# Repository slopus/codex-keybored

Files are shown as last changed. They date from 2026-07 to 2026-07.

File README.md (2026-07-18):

<p align="center">
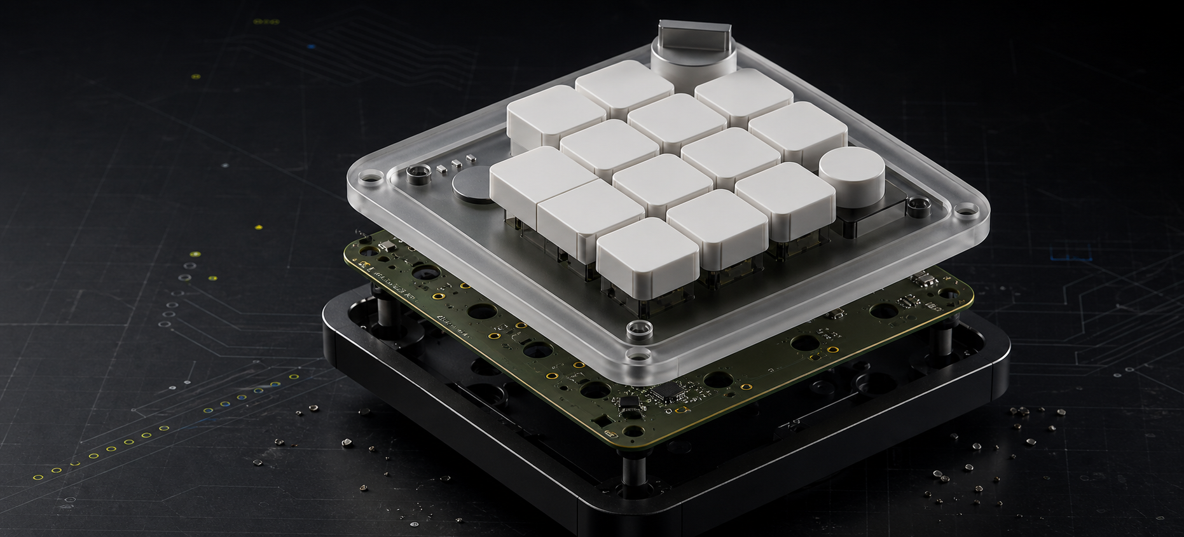
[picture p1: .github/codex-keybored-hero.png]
Exploded CODEX KEYBORED product render showing the CNC enclosure, six-layer PCB, switches, and controls
  
</p>

<h1 align="center">CODEX KEYBORED</h1>
<h3 align="center">WORK LOAFER EDITION · MECHANICS REV B · ELECTRONICS REV A2</h3>

<p align="center">
  A from-scratch, manufacturable parody of the Codex Micro: Fusion 360 mechanics,<br>
  four quoted CNC parts, a wired six-layer PCB, turnkey assembly instructions, and working USB HID firmware.
</p>

<p align="center">
  <a href="https://happy.engineering/codex-keybored/"><b>VIEW THE MANUFACTURING DOSSIER</b></a>
  &nbsp;·&nbsp;
  <a href="output/CODEX_KEYBORED_RevB_order_handoff.zip"><b>DOWNLOAD COMPLETE HANDOFF</b></a>
  &nbsp;·&nbsp;
  <a href="fusion/Codex_Micro_RevA.f3d"><b>OPEN FUSION ARCHIVE</b></a>
</p>

<p align="center">
  
  
  
  
</p>

---

<h1 align="center">THIS IS NOT A DISCLAIMER.<br>THIS IS THE WHOLE POINT.</h1>

<h1 align="center">ABSOLUTELY EVERYTHING HERE IS 100% VIBE-CODED.</h1>

<h1 align="center">
  FROM THE FIRST PROMPT TO FUSION 360, KICAD, GERBERS, FIRMWARE,<br>
  AND A REAL UPLOAD INTO JLCPCB + JLCCNC.
</h1>

<h2 align="center">
  THIS IS THE PRODUCT STORY: ONE CONTINUOUS VIBE<br>
  FROM A PUBLIC PRODUCT IMAGE<br>
  TO A REAL, QUOTED, FACTORY-READY HARDWARE STACK.
</h2>

<p align="center">
  <b>THE DELIGHTFUL PART IS THAT THE VIBE DID NOT STOP WHEN THE WORK BECAME PHYSICAL.</b><br>
  It crossed industrial design, parametric CAD, CNC drawings, multilayer electronics, component sourcing,
  USB firmware, factory testing, pricing, and vendor handoff. Every layer is editable, inspectable, and ready to continue.
</p>

## One vibe, all the way to the factory

Most vibe-coded projects end at a screenshot. This one kept going until the pixels became toleranced solids, the solids became quoted CNC parts, the control layout became a routed six-layer PCB, the PCB became Gerbers/BOM/CPL, the firmware became checksummed factory binaries, and the whole stack became live JLC manufacturing jobs.

That is the fun of this repository: the same conversational build loop moves through every engineering discipline without hiding the seams. “The aluminum base is slightly tilted” became a **5° Fusion body**. “Not a foot, a ring” became a purchased **JIS G‑65 O-ring**, a concentric retention groove, refreshed STEP/DXF/PDF exports, a successful JLCCNC import, a **$68.31** live base quote, and a cleaned cart. “I do not want to solder switches” became a both-side PCBA configuration, consigned-parts manifest, 74-position placement file, manual assembly contract, flashing procedure, and functional acceptance test.

| Vibe-coding pass | What was created | Where it became real |
|---|---|---|
| **Look closely** | Public renders were compared, scaled, and converted into an explicit confirmed/measured/inferred datum set | Research notes + manufacturing dossier |
| **Make it solid** | A parametric 108 × 108 mm assembly, corrected wedge, captured light pipe, joystick cap, and purchased continuous grip ring | Fusion 360 scripts + four STEP/DXF packages + G‑65 vendor reference |
| **Make it electronic** | A clean-room STM32F072 architecture, matrix, USB-C, touch, joystick, 24 RGB pixels, six copper layers | KiCad source + 0-error DRC + IPC netlist |
| **Make it behave** | USB HID firmware, neutral F13–F24 map, RGB safety limit, factory browser test | BIN/HEX/ELF + SHA-256 checksums |
| **Make it buildable** | LCSC mappings, BOM/CPL, specialty-parts sourcing, manual operations, inspection gates | Turnkey factory ZIP + controlled SOP |
| **Make the factory answer** | CAD and fabrication files were uploaded into authenticated quote flows | Four current JLCCNC items + JLCMC G‑65 ring + JLCPCB job Y5 |

```text
PROMPT → RESEARCH → DIMENSIONS → FUSION 360 → STEP/DXF → JLCCNC
                     ↓
              ELECTRICAL PLAN → KICAD → GERBER/BOM/CPL → JLCPCB
                     ↓
              FIRMWARE → FACTORY TEST → TURNKEY HANDOFF → A FEW FINAL SCREWS
```

The result is not “AI made a picture of a keyboard.” The result is a versioned hardware project in which a vibe-driven decision can be traced from sentence to parameter, from parameter to geometry or net, and from production file to a factory price. **That end-to-end continuity is the project.**

---

## The whole device, not just a render

| Mechanical | Electronics | Factory route |
|---|---|---|
| **108 × 108 mm** outer envelope | **90 × 90 mm**, six copper layers | **4 CNC parts** already quoted |
| **5°** machined aluminum wedge | STM32F072 + USB-C + TinyUSB | **5 PCBs / 2 PCBA** in turnkey job Y5 |
| Parametric Fusion assembly + STEP/DXF | 12 keys + encoder + touch + joystick | Specialty parts consigned to the factory |
| Black POM, clear PMMA, 6061-T6, NBR | 24 reverse-mount RGB pixels | Flash, functional test, and evidence in SOP |
| Controlled drawing pack | **0 DRC violations / 0 unconnected nets** | Customer closes only a few enclosure screws |

<table>
  <tr>
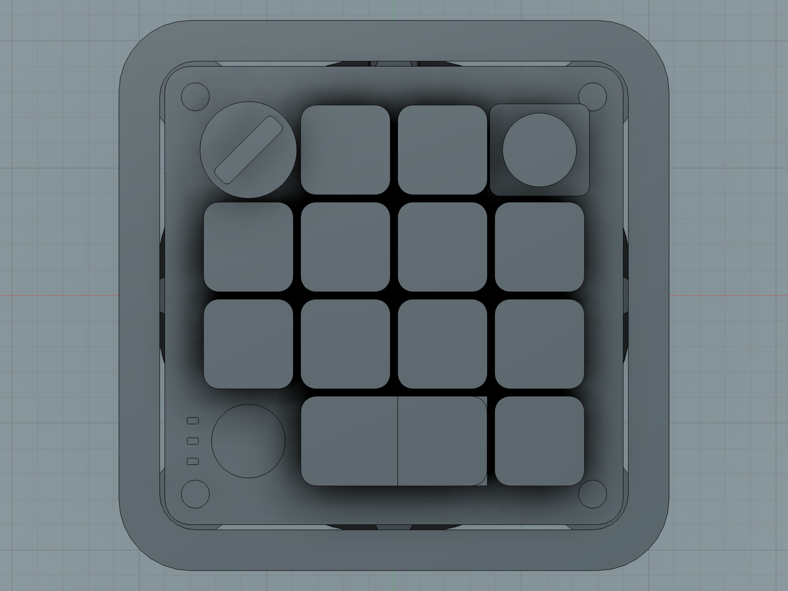
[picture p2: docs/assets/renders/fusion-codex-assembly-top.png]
Fusion 360 top view
    <td width="50%"><br><sub><b>FUSION 360 / TOP</b> — measured mechanical interface</sub></td>
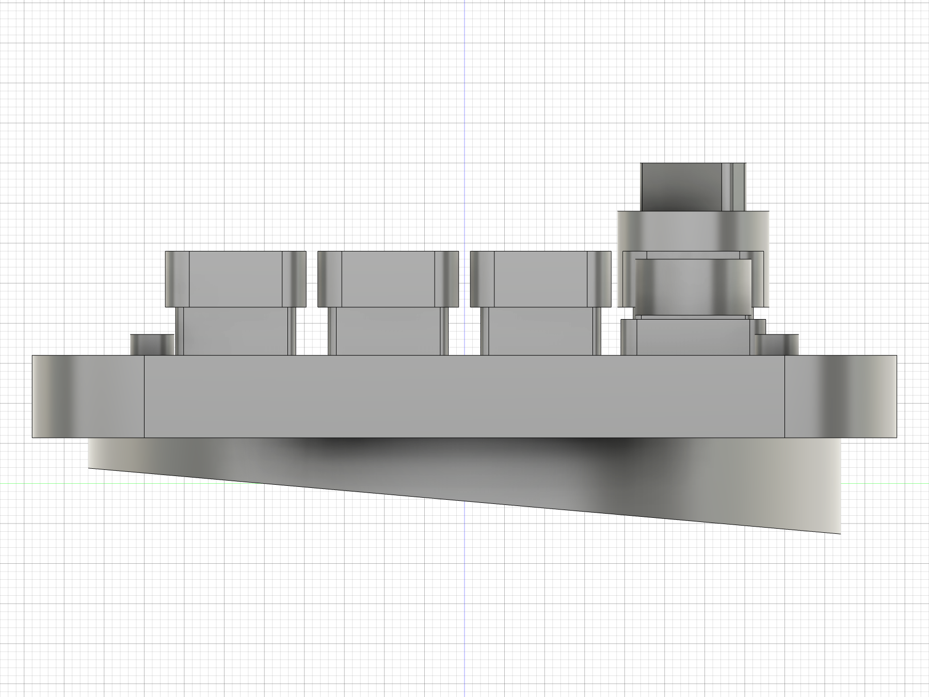
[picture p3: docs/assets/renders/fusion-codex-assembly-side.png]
Fusion 360 side view
    <td width="50%"><br><sub><b>FUSION 360 / SIDE</b> — corrected 5° wedge</sub></td>
  </tr>
  <tr>
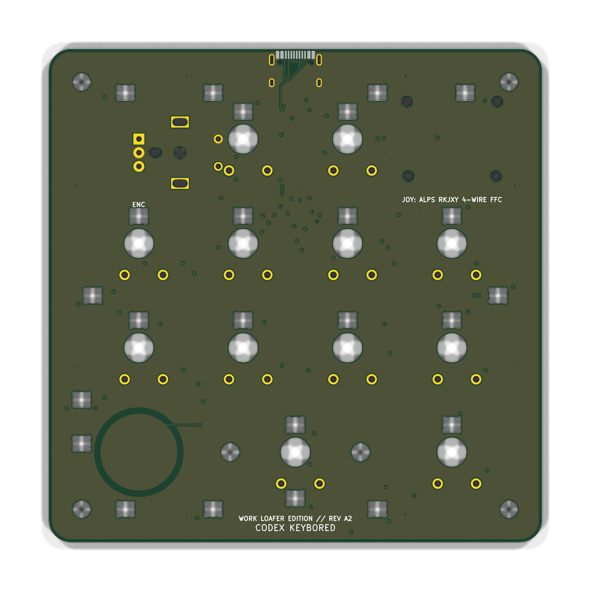
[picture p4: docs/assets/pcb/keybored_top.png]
CODEX KEYBORED PCB top
    <td width="50%"><br><sub><b>PCB / TOP</b> — WORK LOAFER EDITION silk</sub></td>
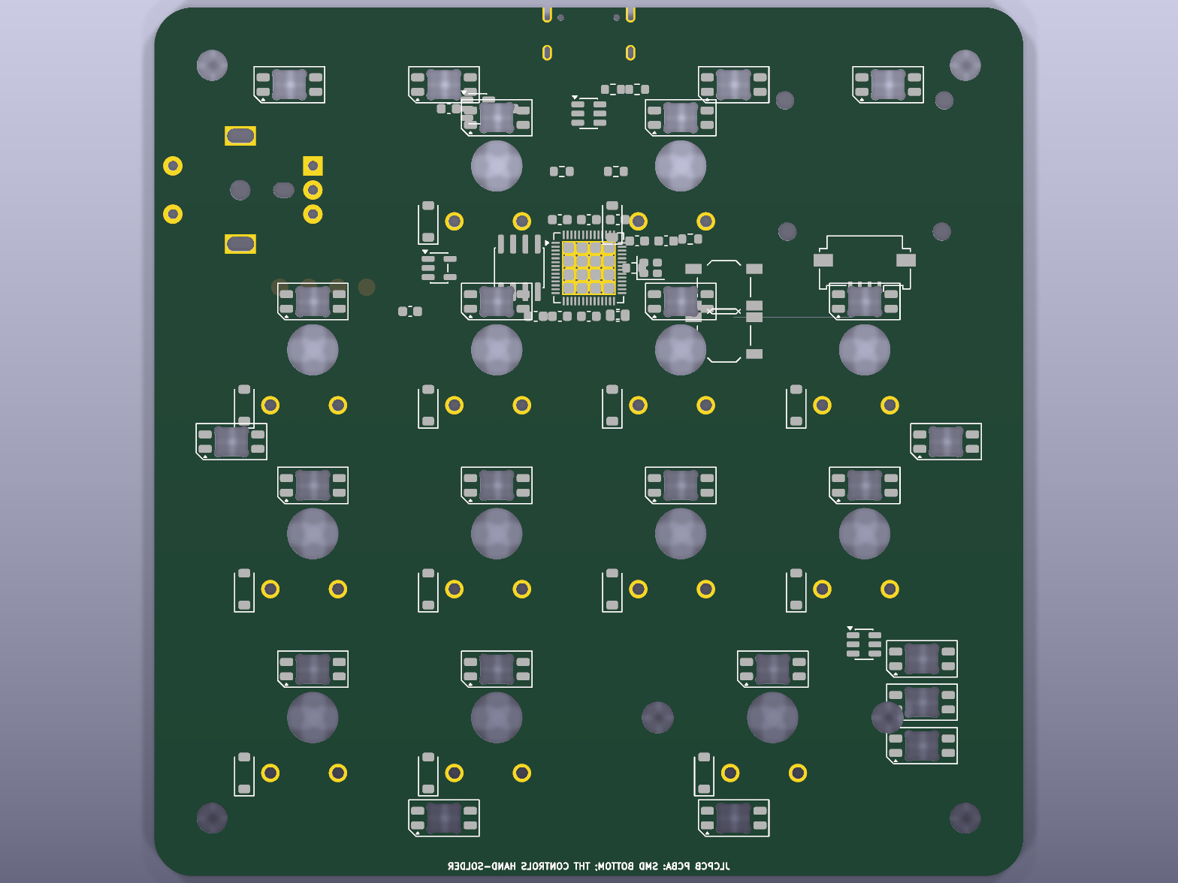
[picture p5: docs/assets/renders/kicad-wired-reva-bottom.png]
Populated PCB underside
    <td width="50%"><br><sub><b>PCB / BOTTOM</b> — controller island, power, matrix, RGB</sub></td>
  </tr>
</table>

## Yes: the factory does the hand work

> **ZERO SOLDERING AT HOME.** The production route asks JLC to place both-side SMD, manually install the twelve switches and encoder, fit the joystick/FFC, flash the STM32, exercise all 20 USB HID events, inspect all 24 RGB emitters, and install the caps on the primary unit. The customer-facing operation is enclosure closure after first-article approval.

The automatic JLC matcher uses the catalog-only [BOM](electronics/production/codex_micro_wired_revA_jlc_bom.csv) and [CPL](electronics/production/codex_micro_wired_revA_jlc_cpl.csv). The complete manual/secondary-operation contract is in the [turnkey SOP](electronics/production/CODEX_KEYBORED_RevA2_TURNKEY_SOP.md), [expanded BOM](electronics/production/codex_micro_wired_revA_turnkey_bom.csv), [74-position CPL](electronics/production/codex_micro_wired_revA_turnkey_cpl.csv), and [consigned-parts manifest](electronics/production/codex_micro_wired_revA_consigned_parts.csv).

```text
SOURCE SPECIALTY PARTS  →  BOTH-SIDE PCBA  →  MANUAL CONTROLS
         →  FLASH + FUNCTION TEST  →  PHOTO EVIDENCE  →  ENCLOSURE CLOSURE
```

## Live manufacturing snapshot

Quotes were captured in an authenticated JLC session on **July 17, 2026**. Prices are dynamic and exclude possible tax, duty, and engineering-review additions.

| Job | Configuration | Captured price |
|---|---|---:|
| CM2-001 upper housing | CNC polished black POM, qty 1 | **$88.97** |
| CM2-002 angled weight | CNC 6061-T6, 5° wedge + G‑65 groove, qty 1 | **$68.31** |
| CM2-003 light pipe | CNC clear cast PMMA, polished edges + frosted face, qty 1 | **$45.70** |
| CM2-004 joystick cap | CNC POM fit prototype, qty 1 | **$19.42** |
| CM2-005 continuous grip ring | JLCMC AMFG-P5-A65-65 / black NBR 65A, qty 1 | **$0.16** |
| **Mechanical subtotal** | Four current CNC parts + purchased ring | **$222.56** |
| **JLCPCB turnkey base** | Five PCBs + two both-side Standard PCBA | **$193.01** |
| **Captured manufacturing floor** | Mechanical merchandise + PCBA base, before manual review, special parts, tax/duty/shipping | **$415.57** |

<p align="center">
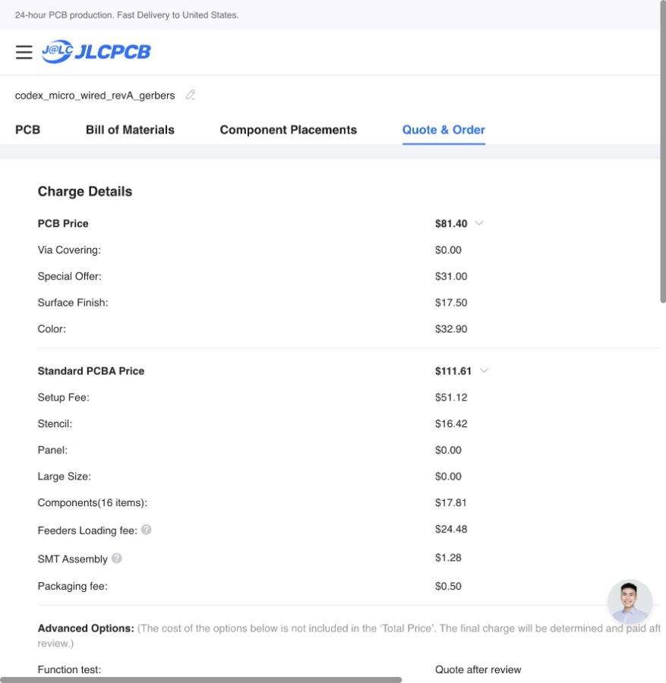
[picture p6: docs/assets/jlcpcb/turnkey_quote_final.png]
JLCPCB turnkey quote configuration
  
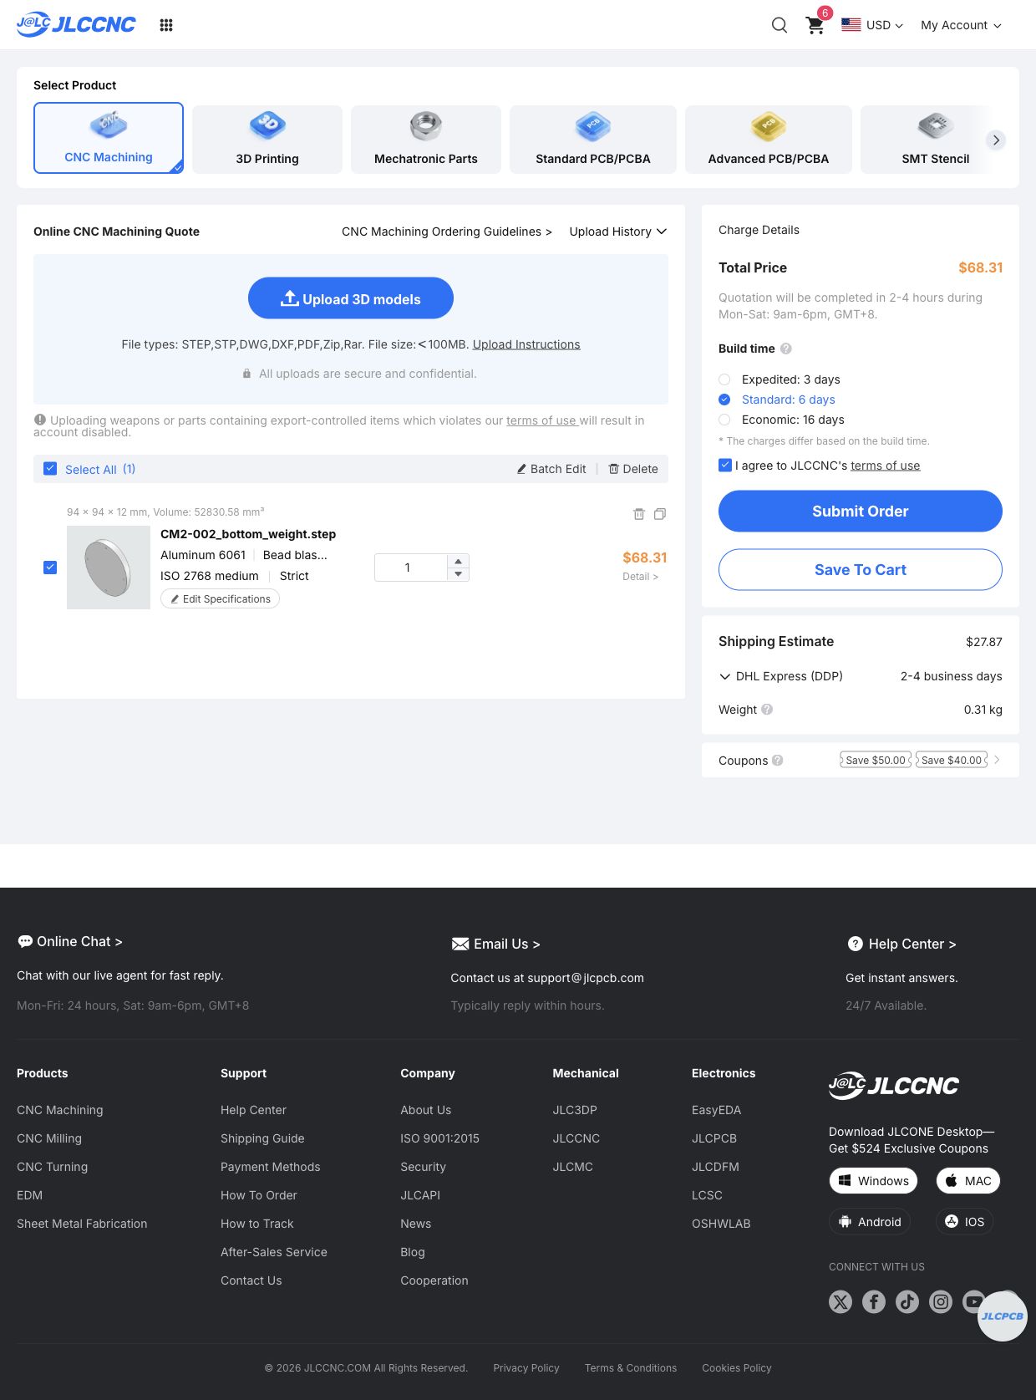
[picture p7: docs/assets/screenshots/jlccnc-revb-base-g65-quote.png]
JLCCNC Rev B ring-groove base quote
  
</p>

The **$193.01** PCB/PCBA figure is a captured base, not a promise of a finished-device total. Programming, functional test, secondary manual operations, and consigned-part handling remain quote-after-review. The saved cart proves that the geometry and six-layer board can enter the vendor workflow; JLC engineering approval is still the gate before payment.

## What is actually in the repository

| Area | Source of truth | Ready-to-send artifact |
|---|---|---|
| Fusion mechanics | [`fusion/build_codex_micro_mechanical.py`](fusion/build_codex_micro_mechanical.py) | [`Codex_Micro_RevA.f3d`](fusion/Codex_Micro_RevA.f3d) |
| CNC geometry | Fusion BRep bodies | [`cnc/STEP/`](cnc/STEP/) + [`cnc/DXF/`](cnc/DXF/) |
| CNC dimensions | Parametric model + controlled notes | [`CM2_CNC_Drawing_Pack_RevB.pdf`](cnc/drawings/CM2_CNC_Drawing_Pack_RevB.pdf) |
| PCB connectivity/layout | [`codex_micro_wired_revA.kicad_pcb`](electronics/kicad/codex_micro_wired_revA.kicad_pcb) | [Gerber/drill ZIP](electronics/production/codex_micro_wired_revA_gerbers.zip) |
| Assembly data | Board-derived generator | [JLC BOM](electronics/production/codex_micro_wired_revA_jlc_bom.csv) + [JLC CPL](electronics/production/codex_micro_wired_revA_jlc_cpl.csv) |
| Principle schematic | Final routed connectivity | [Three-sheet PDF](output/pdf/CODEX_KEYBORED_RevA2_schematic.pdf) + [IPC-D-356](electronics/production/netlist/CODEX_KEYBORED_RevA2.ipc) |
| Firmware | [`firmware/stm32/`](firmware/stm32/) | [BIN](firmware/stm32/release/codeks_keybored_revA.bin) + [HEX](firmware/stm32/release/codeks_keybored_revA.hex) + [checksums](firmware/stm32/release/SHA256SUMS.txt) |
| Factory contract | Mechanics Rev B + electronics Rev A2 | [Complete order handoff ZIP](output/CODEX_KEYBORED_RevB_order_handoff.zip) + [mechanical factory ZIP](output/CODEX_KEYBORED_RevB_mechanical_factory_handoff.zip) |
| Full report | Evidence, screenshots, prices, sources | [Single-page dossier](https://happy.engineering/codex-keybored/) + [Rev B PDF](output/pdf/CODEX-KEYBORED-Manufacturing-Dossier-RevB.pdf) |

## Electrical architecture

- STM32F072CBT6, 128 KB flash, crystal-less HSI48 + CRS USB.
- USB-C device input, dual 5.1 kΩ CC resistors, USBLC6 ESD protection.
- Six layers: `F.Cu`, GND plane, two signal layers, `+5V` plane, `B.Cu`.
- Twelve low-profile matrix switches plus clickable encoder.
- Capacitive touch and two-channel analog planar joystick.
- 24 × SK6812MINI-E: twelve per-key, nine underglow, three status.
- Build-verified TinyUSB firmware with BIN/HEX/ELF artifacts and a browser factory test.
- Housing interface intentionally remains compatible with a future replacement ESP32-S3/BLE board.

<p align="center">
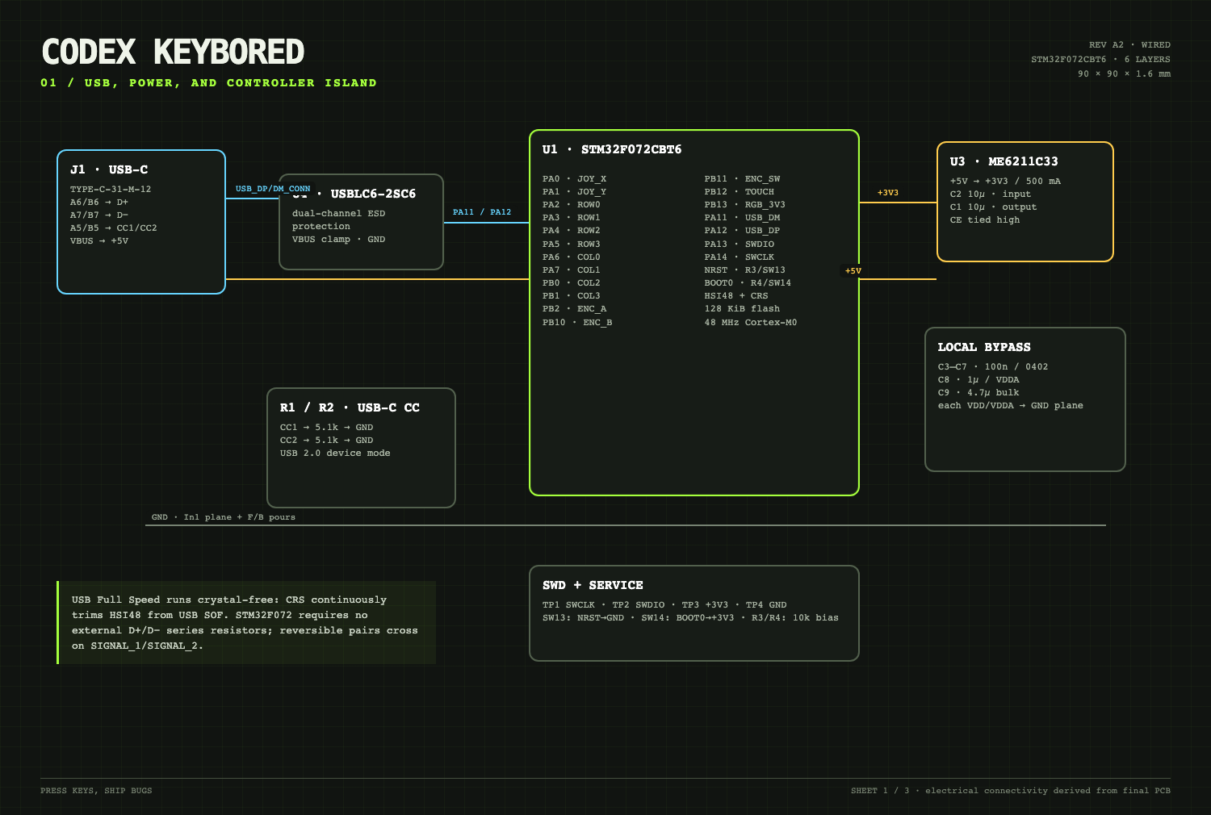
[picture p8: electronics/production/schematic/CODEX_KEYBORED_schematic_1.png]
USB power and STM32 schematic
  
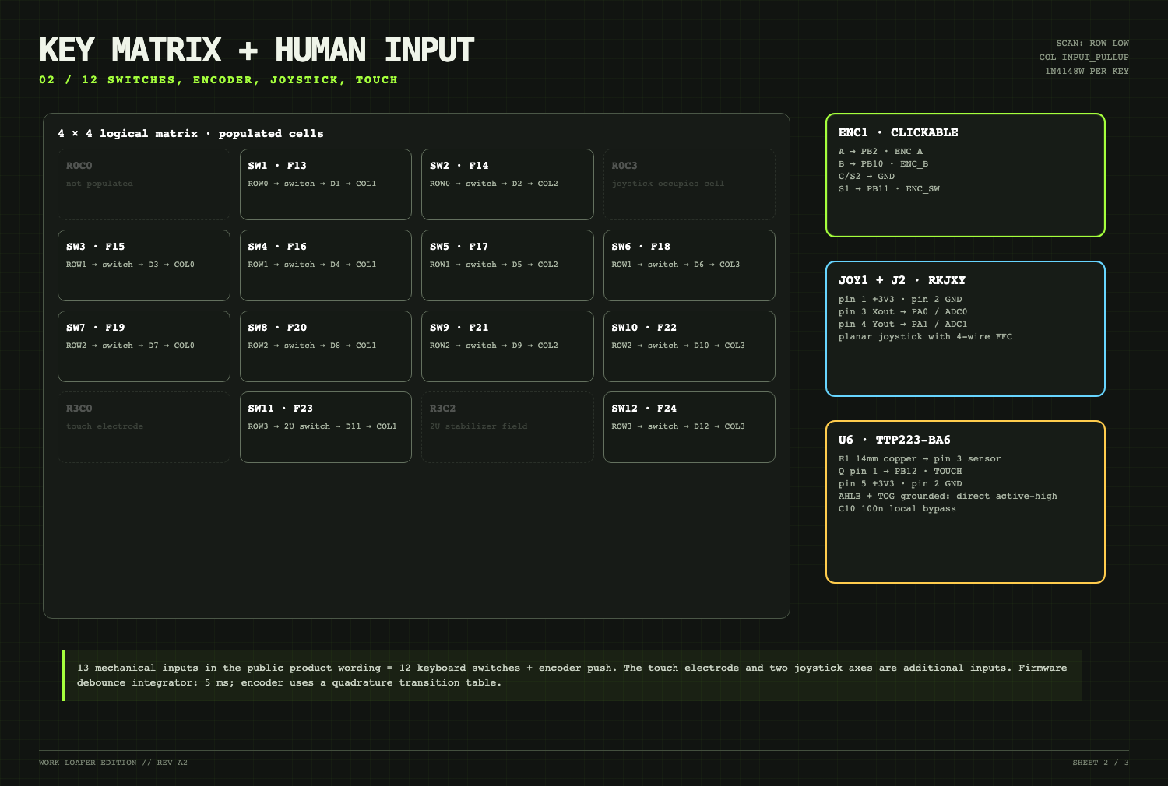
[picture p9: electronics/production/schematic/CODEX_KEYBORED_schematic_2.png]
Keyboard matrix and controls schematic
  
</p>

## Mechanical datum set

The coordinate origin is the device center. `+Y` points toward the rear edge; `+Z` points upward.

| Parameter | Value | Confidence | Basis |
|---|---:|---|---|
| Key pitch | 19.05 mm | **CONFIRMED** | Work Louder MX keycap specification |
| Installed keyboard switches | 12 | **CONFIRMED** | Visible layout + Creator Micro 2 specification |
| Total mechanical switch inputs | 13 | **CONFIRMED** | Includes encoder push |
| Outer envelope | 108 × 108 mm | **MEASURED** | Official top render scaled from key centers |
| Top PCB/panel | 90 × 90 × 1.6 mm | **MEASURED / INFERRED** | Render scale + standard PCB thickness |
| PCB screw pitch | 78 × 78 mm | **MEASURED** | Provisional ±0.5 mm |
| Upper housing | 108 × 108 × 10.3 mm, R14 | **MEASURED** | Public front/side/top renders |
| Aluminum bottom | Ø94 mm, 3.8→12.0 mm, 5° | **MEASURED / INFERRED** | Side profile + CNC construction |
| G‑65 retention groove | Ø67.5 mm centerline × 3.6 W × 2.2 D | **ENGINEERED** | G‑65 section, screw clearance, 1.6 mm minimum Al floor |
| Continuous grip ring | JIS B 2401 G‑65, ID 64.4, section 3.1, OD 70.6 mm | **PURCHASED / VERIFIED** | JLCMC AMFG-P5-A65-65 |
| Joystick candidate | Alps RKJXY1000006 | **CANDIDATE** | Available electrical/mechanical sibling |

Confidence language is deliberate:

- **CONFIRMED** — explicitly published by OpenAI, Work Louder, or a component manufacturer.
- **MEASURED** — scaled from a public, near-orthographic product render.
- **INFERRED** — a manufacturable placeholder that still requires physical first-article inspection.
- **ENGINEERED** — a derived interface sized from known parts, tolerances, and adjacent clearances.
- **PURCHASED / VERIFIED** — an exact orderable catalog part with checked dimensions and a live cart entry.

## CNC material directions

The current quoted Rev B build uses polished black POM for the upper housing and joystick cap, black-anodized 6061-T6 for the 5° base, clear cast PMMA for the captured light pipe, and a purchased black NBR G‑65 ring. A wood upper remains a future material experiment, but it is not the current cart configuration.

All four STEP files passed JLC's automated CNC import. The current bottom was explicitly corrected from an early flat disc to the observed **5° wedge**, then revised again with the G‑65 retention groove before the **$68.31** configuration was saved. Obsolete flat/no-groove parts and individual rubber feet were removed from the cart.

## Reproduce it

1. Open or create the Fusion document named `Codex`, then run [`fusion/build_codex_micro_mechanical.py`](fusion/build_codex_micro_mechanical.py).
2. Export/audit CNC bodies with the scripts in [`fusion/`](fusion/) and compare them with the controlled drawing pack.
3. Open the board in KiCad 10 and verify the committed DRC report before regenerating fabrication data.
4. Build the STM32 target from [`firmware/stm32/`](firmware/stm32/) or use the checksummed release image.
5. Upload the Gerber ZIP, JLC BOM/CPL, CNC STEP files, drawing pack, and turnkey factory ZIP.
6. Do not authorize production until JLC DFM, polarity/rotation, manual-operation scope, and first-article dimensions are reviewed.

## Prototype status and provenance

This is an **independent private prototype**, reconstructed from official public product renders and published platform/component documentation. It is not an official OpenAI or Work Louder CAD/electronics release, is not affiliated with or endorsed by either company, and contains no leaked manufacturing data.

The digital production gate is clean: Gerbers, drill files, BOM/CPL, IPC netlist, three-sheet principle schematic, firmware, STEP/DXF, drawings, and vendor quote evidence are present. The physical gate is still open: no fabricated Rev A2 board has completed electrical bring-up, EMC evaluation, or dimensional fit-check. Use a current-limited supply, verify the 3.3 V rail and SWD first, and treat the first order as an engineering prototype.

Primary research links and detailed source notes live in the [manufacturing dossier](https://happy.engineering/codex-keybored/) and [`firmware-and-compliance-notes.md`](firmware-and-compliance-notes.md).

---

<h2 align="center">PRESS KEYS. SHIP BUGS.</h2>
<p align="center"><b>CODEX KEYBORED / WORK LOAFER EDITION / MECHANICS REV B + ELECTRONICS REV A2</b></p>

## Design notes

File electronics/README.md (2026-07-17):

# CODEX KEYBORED Wired Rev A2 — production notes

This directory contains a mechanically compatible **wired prototype**, not a
reverse-engineered copy of the unpublished Work Louder electronics.  The board
uses a clean-room STM32F072/USB-C design and keeps the 90 × 90 mm top-panel outline
so a later ESP32-S3/BLE controller can replace it without changing the housing.

## Electrical architecture

- Six copper layers: `F.Cu`, ground plane, two signal layers, `+5V` plane,
  `B.Cu`.
- STM32F072CBT6 with 128 KB internal flash, HSI48 + CRS crystal-less USB, and
  ME6211 3.3 V LDO. No external flash or crystal is required.
- USB-C device input with two 5.1 kΩ CC resistors and USBLC6 ESD protection.
  The reversible connector pairs cross on `SIGNAL_1` / `SIGNAL_2` before PA11/PA12.
- Twelve Gateron KS-33 / wrk. LP1-family matrix switches plus encoder push.
- Clickable encoder, TTP223-class touch input and two-channel analog joystick.
- 24 SK6812MINI-E pixels through a 5 V-compatible AHCT buffer: 12 per-key,
  nine perimeter underglow and three status LEDs.
- NRST, BOOT0 and SWD bring-up access.

The PCB is generated from `generate_wired_reva.py`; it deliberately does not
depend on a GUI schematic editor. Pad/net assignments in the generated KiCad
board are the electrical source of truth. `generate_jlc_outputs.py` derives the
assembly files from that same board and fails if an unmapped fitted reference is
encountered.

Final automated checks report **0 DRC violations and 0 unconnected nets**.
`docs/schematic.html` is a three-sheet engineering principle schematic derived
from that final connectivity; the IPC-D-356 file is the machine-readable netlist.

## Production files

- `production/codex_micro_wired_revA_gerbers.zip` — JLCPCB fabrication upload.
- `production/codex_micro_wired_revA_jlc_bom.csv` — JLCPCB BOM with LCSC IDs.
- `production/codex_micro_wired_revA_jlc_cpl.csv` — machine placement file.
- `production/codex_micro_wired_revA_turnkey_bom.csv` — both-side BOM including
  consigned/manual controls and factory-programming buttons.
- `production/codex_micro_wired_revA_turnkey_cpl.csv` — all 74 machine and
  manual placement centers.
- `production/codex_micro_wired_revA_consigned_parts.csv` — direct-to-JLC
  sourcing quantities for WRK-LP1, joystick, keycaps, and dial cap.
- `production/CODEX_KEYBORED_RevA2_TURNKEY_SOP.md` — assembly, programming,
  functional test, evidence, and delivery acceptance instructions.
- `production/codex_micro_wired_revA_hand_assembly.csv` — legacy list of parts
  omitted by the saved bottom-only baseline quote.
- `production/codex_micro_wired_revA_drc.json` — final clean DRC report.
- `production/netlist/CODEX_KEYBORED_RevA2.ipc` — IPC-D-356 connectivity.
- `production/schematic/CODEX_KEYBORED_RevA2_schematic.pdf` — principle schematic.

JLC cart job Y5 / `SMT026071763199-3086316A` is Standard PCBA on **both sides**:
five PCBs and two assembled boards. Its automatic matcher uses the catalog-only
`*_jlc_bom.csv` and `*_jlc_cpl.csv` and confirmed all 16 groups. The expanded
`turnkey` BOM/CPL and consigned-parts CSV are factory engineering references for
manual installation of `SW1–SW12`, the encoder, and the joystick/FFC. The
captured base is $193.01; programming, FCT, and manual engineering remain
quote-after-review. These are contract-assembly operations—not customer work.
Review every polarity/rotation and obtain JLC engineering approval before
confirming a paid order.

## Bring-up gate

This is a prototype design and has not been electrically tested on fabricated
hardware. Before attaching a computer, use a current-limited 5 V supply and
verify the 3.3 V rail, inspect for shorts, confirm SWD/NRST, and only then
enumerate USB. The supplied firmware limits
RGB channels to 4/255; still populate the chain last, or depopulate its bulk
capacitor/level shifter for the earliest rail-only bring-up.

The selected LCSC mappings and exact quantities are listed in the BOM. Part
stock and JLCPCB assembly classification can change; a successful web quote is
not an engineering substitute for the vendor's final DFM and placement review.

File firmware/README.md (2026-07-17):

# CODEX KEYBORED firmware

The production Rev A2 target is the STM32F072CBT6 project in [`stm32/`](stm32/).
It enumerates as a driverless USB HID keyboard and implements the complete PCB
pin map: 12-key matrix, clickable encoder, capacitive touch, two-axis joystick
ADC and a conservative 24-pixel SK6812 status/underglow chain.

The older root-level RP2040 proof-of-concept sources and `release/` binaries are
retained only as design history. They **must not** be flashed onto Rev A2.

See [`stm32/README.md`](stm32/README.md) for the reproducible build, SWD flash
command and first-power checklist.

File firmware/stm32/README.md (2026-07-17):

# STM32F072 wired Rev A2

This build targets the directly assembled STM32F072CBT6 on the single 90 x 90
mm PCB. USB Full Speed uses the internal HSI48 oscillator disciplined by CRS;
there is no crystal and no removable controller module.

## Behavior

- 12 keys send F13–F24 in physical order.
- Encoder rotation sends Page Up/Page Down; push sends keypad Enter.
- Capacitive touch sends F12.
- Joystick thresholds send the four arrow keys.
- 24 SK6812MINI-E pixels are limited to channel values 0–4/255 during bring-up.
- USB identity: development VID/PID `CAFE:4B44`, product `CODEX KEYBORED Rev A2`.

## Reproducible build

TinyUSB is pinned at commit `aa410008e8e74b0727f8c30a1ec109ff2c37efc6`.
The large upstream checkout is intentionally not stored in this repository;
the tracked bootstrap script fetches only the required STM32F0 dependencies and
installs the local `codeks_keybored` board definition. Use an Arm GNU embedded
toolchain that includes newlib (verified with official Arm GNU Toolchain
15.2.Rel1):

```sh
sh firmware/stm32/fetch_dependencies.sh
cmake -S firmware/stm32 -B firmware/stm32/build-arm15 -G Ninja \
  -DFAMILY=stm32f0 -DBOARD=codeks_keybored -DTOOLCHAIN=gcc
cmake --build firmware/stm32/build-arm15 -j
```

The verified build uses 16,548 bytes of 128 KiB flash and 2,448 bytes of 16 KiB
RAM. Flash `release/codeks_keybored_revA.hex` through SWD (TP1 SWCLK, TP2 SWD,
TP3 3V3, TP4 GND), for example:

```sh
openocd -f interface/stlink.cfg -f target/stm32f0x.cfg \
  -c "program release/codeks_keybored_revA.hex verify reset exit"
```

## Verification boundary

The artifacts are compiler/linker verified, not hardware verified. Power the
first assembly from a current-limited 5 V supply before attaching a computer.
Confirm 3.3 V, SWD access, USB enumeration, every switch/encoder direction,
joystick center/endpoints, touch polarity and all RGB orientations. The
bit-banged SK6812 timing is deliberately isolated in `main.c`; verify it on an
oscilloscope and tune the delay constants for the assembled board before
raising brightness. Replace the development USB VID/PID before distribution.

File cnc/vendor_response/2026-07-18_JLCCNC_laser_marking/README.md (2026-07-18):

# JLCCNC laser-marking response — CM2-002 Rev B

This package answers JLCCNC's request to replace the too-fine machined lettering on the black-anodized aluminum bottom weight with laser marking.

## Send these three files

1. `CM2-002_LASER_ARTWORK_ONLY_RevB.dxf` — production laser artwork only. This is the safest file for import into the laser CAM system.
2. `CM2-002_LASER_PLACEMENT_REFERENCE_RevB.dxf` — the same artwork plus Ø94 part outline, groove, holes, and rear datum on clearly named `DO_NOT_MARK` layers.
3. `CM2-002_LASER_PLACEMENT_APPROVAL_RevB.pdf` — human-readable 1:1 approval sheet specifying side, orientation, process order, and appearance.

Copy the body of `EMAIL_REPLY.txt` into the reply email and attach the three files individually. Do not rely on the ZIP alone if their mail gateway blocks archives.

## Controlled manufacturing intent

- Part: `CM2-002_bottom_weight.step`
- CNC item: `CNC2607185001881-3086316A`
- Surface: underside / desk-facing angled plane
- Orientation: `+Y` is rear / thick edge / USB side
- Process: fine bead blast → black matte anodize → laser mark
- Appearance: natural aluminum / silver artwork on black
- Marking: solid/hatch-filled compound glyphs, with letter counters preserved
- Production layer: `LASER_MARK` only
- Coordinates: millimeters, scale 1:1, origin at part center
- Main line: `CODEX KEYBORED`, Arial Bold, 4.2 mm nominal CAD font size; outlined envelope 39.498 × 3.109 mm; center `(0, +4.000)`
- Strapline: `ABSOLUTELY VIBE-CODED`, Arial Regular, 2.1 mm nominal CAD font size; outlined envelope 27.122 × 1.556 mm; center `(0, −4.000)`

The DXFs contain no live font objects. The artwork consists of closed `LWPOLYLINE` contours so the factory does not need the source fonts.

## Reference-only files

- `CM2-002_LASER_PLACEMENT_PREVIEW_RevB.svg` — screen preview.
- `CM2-002_LASER_GEOMETRY_RevB.json` — machine-readable source geometry and measured bounds.

These are included for traceability but do not need to be emailed unless requested.

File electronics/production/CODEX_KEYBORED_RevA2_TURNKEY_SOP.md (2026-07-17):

# CODEX KEYBORED Rev A2 — turnkey assembly and test SOP

**Build intent:** deliver one complete, programmed, electrically tested control pad and one programmed spare PCBA. The customer performs no soldering. Home assembly is limited to the controlled enclosure screws after first-article fit approval.

## Order configuration

- Service: JLCPCB **Standard PCBA**, both sides.
- Fabrication: 6-layer FR-4, 90 × 90 × 1.6 mm, white mask, black silk, ENIG.
- PCB quantity: 5. PCBA quantity: 2.
- Submit `codex_micro_wired_revA_jlc_bom.csv` and `codex_micro_wired_revA_jlc_cpl.csv` to JLC's automatic catalog matcher. Use the expanded `turnkey` BOM/CPL and consigned-parts CSV as the manual-assembly engineering reference.
- Depanel and remove JLC edge rails before delivery.
- Enable component photo confirmation, programming/function test, and a PCBA remark referencing this SOP.
- Customer-consigned parts must be received and booked into the JLC parts library before production.

## Assembly sequence

1. Assemble all bottom-side SMD parts, including reverse-mount RGB LEDs, J2, RESET, and BOOT0.
2. Assemble the top-side USB-C connector J1.
3. Manually insert and solder twelve WRK-LP1 switches at SW1–SW12. Seat every switch body flush and square to the PCB before soldering.
4. Manually insert and solder EC11E09444A8 at ENC1. Keep the shaft normal to the PCB.
5. Mechanically install RKJXY1000006 at JOY1 and lock its four-wire flex tail into J2. Do not crease the tail.
6. Clean and visually inspect all manual joints. Verify no switch body is lifted by more than 0.15 mm and the 2U key remains centered over SW11.
7. Program both PCBAs, run the functional test below, and identify the passing units as PRIMARY and SPARE.
8. On PRIMARY only, fit the twelve final keycaps, the 2U stabilizer/cap, the dial cap, and the joystick cap after electrical test. Do not glue caps.
9. Bag PRIMARY and SPARE separately in ESD-safe packaging. Include unused switches and unused PCB blanks.

## Firmware programming

- Target: STM32F072CBT6.
- Image: `../../firmware/stm32/release/codeks_keybored_revA.bin` at address `0x08000000`, or the corresponding HEX file.
- Preferred production route: SWD pogo contact at TP1/TP2/TP3/TP4 (SWCLK/SWDIO/3V3/GND).
- Alternate route: hold BOOT0 (SW14), pulse RESET (SW13), release BOOT0 after USB DFU enumerates, then program with STM32CubeProgrammer.
- After programming, power-cycle and confirm USB HID enumeration as `CODEX KEYBORED`.

## Functional acceptance test

Open `../../firmware/factory_key_test.html` in a Chromium browser on the test host, focus the page, then exercise every control.

- SW1–SW12: all F13–F24 indicators must pass exactly once.
- Encoder push: Keypad Enter indicator must pass.
- Encoder clockwise/counter-clockwise: Page Up and Page Down must both pass.
- Joystick: Left, Right, Up, and Down must all pass and return to neutral.
- Touch pad: F12 indicator must pass.
- RGB: all 24 emitters must illuminate; installed-key LEDs change state when their key is pressed.
- USB: reconnect three times; the device must enumerate each time without a warning.
- No switch may chatter visibly in the browser tester during ten presses.

Save one photo of the completed PRIMARY top side, one bottom-side photo, and one screenshot of the all-green factory tester. Do not ship a failed unit as PRIMARY.

## Customer-side work

After dimensional first-article approval, the customer only installs the completed PRIMARY PCBA/light pipe into the CNC parts using the four specified enclosure screws. No soldering, firmware flashing, switch insertion, or key testing is assigned to the customer.

## Quote status

JLC cart job Y5 / `SMT026071763199-3086316A` is configured for five PCBs and two both-side Standard PCBA units. Its captured base is `$193.01` (`$81.40` PCB + `$111.61` PCBA). Function testing, the PCBA remark/manual work, and consigned WRK-LP1/RKJXY operations remain quote-after-review; the base is not the final turnkey price.

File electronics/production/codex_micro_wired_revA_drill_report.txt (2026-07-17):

Drill report for codex_micro_wired_revA.kicad_pcb
Created on 2026-07-17T12:11:25

Copper Layer Stackup:
    =============================================================
    L1 :  F.Cu                      front
    L2 :  GND_PLANE                 in1
    L3 :  SIGNAL_1                  in2
    L4 :  SIGNAL_2                  in3
    L5 :  +5V_PLANE                 in4
    L6 :  B.Cu                      back

Drill file 'codex_micro_wired_revA-PTH.drl' contains
    plated through holes:
    =============================================================
    T1  0.200mm  0.0079"  (94 holes))
    T2  0.300mm  0.0118"  (8 holes))
    T3  0.600mm  0.0236"  (4 holes)  (with 4 slots)
    T4  1.000mm  0.0394"  (5 holes))
    T5  1.200mm  0.0472"  (24 holes))
    T6  1.500mm  0.0591"  (2 holes)  (with 2 slots)

    Total plated holes count 137

Drill file 'codex_micro_wired_revA-NPTH.drl' contains
    unplated through holes:
    =============================================================
    T1  0.650mm  0.0256"  (2 holes))
    T2  1.600mm  0.0630"  (1 hole)  (with 1 slot)
    T3  1.900mm  0.0748"  (4 holes))
    T4  2.100mm  0.0827"  (1 hole)
    T5  3.200mm  0.1260"  (4 holes))
    T6  3.300mm  0.1299"  (2 holes))
    T7  5.300mm  0.2087"  (12 holes))

    Total unplated holes count 26

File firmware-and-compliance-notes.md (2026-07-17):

# Firmware, Bluetooth, FCC, and ISED evidence

## Public firmware inspected

Work Louder published a diagnostic CM2 image in its battery-charging support
thread:

`https://github.com/worklouder/input-releases-internal/releases/download/battery.charging.diagnostic/firmware_cmv2_v0.3.0-rc.2_merged.bin`

`esptool 5.2.0 image-info` identifies the 2,117,568-byte merged image as:

- target: **ESP32-S3** (chip ID 9);
- flash: **16 MB**, DIO, 80 MHz;
- bootloader: ESP-IDF **5.3.2.250210**;
- compile time: 2026-01-16 11:32:52;
- image checksum and SHA-256 validation hash both valid.

Selected plain-text symbols/strings in the image:

- `Work Louder`, `Creator Micro 2`;
- `NimBLE`, `TinyUSB`, `ESP32 Keyboard`;
- `max77972_regs`, `Initializing battery IC`;
- GPIO initialization for rear button, USB detect, layer LEDs, touch pad,
  encoder A/B/switch, top-board power, and charge enable;
- `Switching to BLE slot %d`;
- self-test for key matrix, encoder rotation/press, touch button, rear button,
  and battery voltage/current;
- default keymap rows of 2 / 4 / 4 / 3 keyboard inputs.

Analog Devices describes MAX77972 as a one-cell Li-ion/Li-poly charger and fuel
gauge with USB-C CC and BC1.2 detection:
`https://www.analog.com/en/products/MAX77972.html`.

The binary proves the MCU family and charger IC used by the firmware build. It
does **not** prove whether production uses a bare ESP32-S3, an Espressif module,
or a custom certified radio module.

## FCC result

The official FCC EAS grantee-registration dataset was searched for:

- `Work Louder`
- `Worklouder`
- `Louder`
- `Creator Micro`
- `3300 Av Troie`

All returned zero records. The official exterior bottom render carries an FCC
logo but no visible FCC ID. This is consistent with, but does not prove, use of
a pre-certified radio module or a compliance route that does not create a Work
Louder grantee entry.

Official FCC grantee dataset:
`https://opendata.fcc.gov/resource/3b3k-34jp.json`

## Canadian ISED result

The official ISED Company Name Search returned no result for `Work Louder`.
The official Radio Equipment List returned no result for either:

- Product Marketing Name: `Creator Micro 2`
- Company Name: `Work Louder`

Search entry point:
`https://www.ised-isde.canada.ca/site/spectrum-management-system/en/equipment-certification-and-registration-services`

## What will resolve the radio module exactly

The next definitive evidence is a straight-on macro photograph of both sides of
the lower PCB after lifting the four top screws and disconnecting the FFC. The
required details are the ESP/module shield marking, antenna layout, FCC/ISED
text, crystal marking, USB-C connector, and MAX77972 area. Until that image
exists, the PCB should reserve a certified ESP32-S3 module keep-out rather than
copy an unverified antenna implementation.

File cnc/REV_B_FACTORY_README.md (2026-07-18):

# CODEX KEYBORED — Mechanical Rev B factory handoff

This package is the controlled mechanical first-article set for one device.
Submit four custom parts to JLC CNC and purchase one standard continuous grip
ring from JLCMC. Do not substitute individual rubber feet.

## Order exactly these items

| ID | File / part number | Qty | Material and finish | Live price 2026-07-17 |
|---|---|---:|---|---:|
| CM2-001 | `STEP/CM2-001_upper_housing.step` | 1 | POM (Black); no bead blast; polish cosmetic A-surfaces | $88.97 |
| CM2-002 | `STEP/CM2-002_bottom_weight.step` | 1 | 6061-T6; fine bead blast + matte black anodize; strict appearance | $68.31 |
| CM2-003 | `STEP/CM2-003_lightpipe.step` | 1 | Clear cast PMMA; transparent-polished edges; fine-frost top optical face | $45.70 |
| CM2-004 | `STEP/CM2-004_joystick_cap.step` | 1 | POM (Black); no surface finish | $19.42 |
| CM2-005 | JLCMC `AMFG-P5-A65-65` | 1 | JIS B 2401 G-65; black NBR; 65 Shore A | $0.1522 |

Mechanical merchandise subtotal at the captured prices: **$222.56** before
shipping, tax, duty, and engineering review. Prices are dynamic.

## Drawing association

Attach the matching PDF to each CNC line item:

- CM2-001 → `drawings/CM2-001_Drawing_RevB.pdf`
- CM2-002 → `drawings/CM2-002_Drawing_RevB.pdf`
- CM2-003 → `drawings/CM2-003_Drawing_RevB.pdf`
- CM2-004 → `drawings/CM2-004_Drawing_RevB.pdf`

The consolidated pack is `drawings/CM2_CNC_Drawing_Pack_RevB.pdf`. Its fifth
sheet defines the purchased ring and groove interface; CM2-005 is not a custom
machined or printed part.

## Critical Rev B interface

- Aluminum base envelope: Ø94 mm, 3.8 mm front to 12.0 mm rear, nominal 5°.
- G-65 groove: Ø67.5 mm centerline, 3.6 mm width, 2.2 mm depth.
- Purchased ring: 64.4 ±0.57 mm ID, 3.1 ±0.10 mm section, 70.6 mm nominal OD.
- Ring protrusion: 0.9 mm nominal. No adhesive.
- Minimum aluminum floor below groove: 1.6 mm.
- Groove-to-counterbore radial land: 2.95 mm.
- Base fasteners: one M2.5×8 front, two M2.5×12 sides, one M2.5×16 rear.

## First-article acceptance

1. Inspect all four custom parts against their controlled drawing PDFs.
2. Dry-fit the G-65 ring; it must remain continuously captured while standing
   approximately 0.9 mm proud without adhesive.
3. Verify the base sits on the ring rather than on anodized aluminum or screw
   heads and does not rock on a flat reference surface.
4. Verify the PMMA light pipe seats in the POM pocket without force and its rear
   USB gap aligns with the housing notch.
5. Gauge M3 and M2.5 threads, then assemble with the four specified screw
   lengths at low torque.
6. Approve one physical first article before ordering multiples.

The authoritative machine-readable values are in `rev_b_spec.json`; the
independent geometry audit is in `rev_b_fit_report.json` and must report
`"status": "PASS"`.

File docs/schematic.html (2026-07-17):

# CODEX KEYBORED

## 01 / USB, power, and controller island

REV A2 · WIRED
STM32F072CBT6 · 6 LAYERS
90 × 90 × 1.6 mm

J1 · USB-CTYPE-C-31-M-12
A6/B6 → D+
A7/B7 → D−
A5/B5 → CC1/CC2
VBUS → +5V

U4 · USBLC6-2SC6dual-channel ESD protection
VBUS clamp · GND

U1 · STM32F072CBT6 PA0 · JOY_X
PA1 · JOY_Y
PA2 · ROW0
PA3 · ROW1
PA4 · ROW2
PA5 · ROW3
PA6 · COL0
PA7 · COL1
PB0 · COL2
PB1 · COL3
PB2 · ENC_A
PB10 · ENC_B
PB11 · ENC_SW
PB12 · TOUCH
PB13 · RGB_3V3
PA11 · USB_DM
PA12 · USB_DP
PA13 · SWDIO
PA14 · SWCLK
NRST · R3/SW13
BOOT0 · R4/SW14
HSI48 + CRS
128 KiB flash
48 MHz Cortex-M0

U3 · ME6211C33+5V → +3V3 / 500 mA
C2 10µ · input
C1 10µ · output
CE tied high

LOCAL BYPASSC3–C7 · 100n / 0402
C8 · 1µ / VDDA
C9 · 4.7µ bulk
each VDD/VDDA → GND plane

R1 / R2 · USB-C CCCC1 → 5.1k → GND
CC2 → 5.1k → GND
USB 2.0 device mode

SWD + SERVICETP1 SWCLK · TP2 SWDIO · TP3 +3V3 · TP4 GND
SW13: NRST→GND · SW14: BOOT0→+3V3 · R3/R4: 10k bias

USB_DP/DM_CONN

PA11 / PA12

+5V

+3V3

GND · In1 plane + F/B pours

USB Full Speed runs crystal-free: CRS continuously trims HSI48 from USB SOF. STM32F072 requires no external D+/D− series resistors; reversible pairs cross on SIGNAL_1/SIGNAL_2.

PRESS KEYS, SHIP BUGSSHEET 1 / 3 · electrical connectivity derived from final PCB

# KEY MATRIX + HUMAN INPUT

## 02 / 12 switches, encoder, joystick, touch

SCAN: ROW LOW
COL INPUT_PULLUP
1N4148W PER KEY

### 4 × 4 logical matrix · populated cells

R0C0not populated

SW1 · F13ROW0 → switch → D1 → COL1

SW2 · F14ROW0 → switch → D2 → COL2

R0C3joystick occupies cell

SW3 · F15ROW1 → switch → D3 → COL0

SW4 · F16ROW1 → switch → D4 → COL1

SW5 · F17ROW1 → switch → D5 → COL2

SW6 · F18ROW1 → switch → D6 → COL3

SW7 · F19ROW2 → switch → D7 → COL0

SW8 · F20ROW2 → switch → D8 → COL1

SW9 · F21ROW2 → switch → D9 → COL2

SW10 · F22ROW2 → switch → D10 → COL3

R3C0touch electrode

SW11 · F23ROW3 → 2U switch → D11 → COL1

R3C22U stabilizer field

SW12 · F24ROW3 → switch → D12 → COL3

ENC1 · CLICKABLEA → PB2 · ENC_A
B → PB10 · ENC_B
C/S2 → GND
S1 → PB11 · ENC_SW

JOY1 + J2 · RKJXYpin 1 +3V3 · pin 2 GND
pin 3 Xout → PA0 / ADC0
pin 4 Yout → PA1 / ADC1
planar joystick with 4-wire FFC

U6 · TTP223-BA6E1 14mm copper → pin 3 sensor
Q pin 1 → PB12 · TOUCH
pin 5 +3V3 · pin 2 GND
AHLB + TOG grounded: direct active-high
C10 100n local bypass

13 mechanical inputs in the public product wording = 12 keyboard switches + encoder push. The touch electrode and two joystick axes are additional inputs. Firmware debounce integrator: 5 ms; encoder uses a quadrature transition table.

WORK LOAFER EDITION // REV A2SHEET 2 / 3

# RGB + PIN MAP + BUILD GATE

## 03 / addressable lighting and production truth

24 × SK6812MINI-E
5V DATA LEVEL
100µF BULK

### Data chain

PB13
RGB_3V3

→

U5
74AHCT1G125
3.3 → 5V

→

LED1
key 1

→

LED2…11
keys 2–11

→

LED12
key 12

→

LED13…21
underglow ×9

→

LED22…24
status ×3

All pixels: pin 1 +5V · pin 3 GND · reverse-mount routed window 3.38 × 2.98 mm. C19 = 100µF/6.3V at LED rail. U5 OE is tied low.

### STM32F072CBT6 LQFP48 pin allocation

Pin group | Signal | Function
PA0 / PA1 | JOY_X / JOY_Y | 12-bit ADC
PA2…PA5 | ROW0…ROW3 | matrix row drive
PA6, PA7, PB0, PB1 | COL0…COL3 | matrix sense, pull-up
PB2 / PB10 / PB11 | ENC_A/B/SW | quadrature + click
PB12 / PB13 | TOUCH / RGB_3V3 | touch input / LED data
PA11 / PA12 | USB_DM / USB_DP | USB Full Speed
PA13 / PA14 | SWDIO / SWCLK | program + debug
VBAT, VDDA, VDD×3 | +3V3 | local bypass C3–C9
VSSA, VSS×3 | GND | dedicated In1 plane

### Manufacturing gate

PCB | 90 × 90 mm · 6 layer · 1.6 mm
Rules | 0.15 mm route · 0.10 mm clearance
Vias | 0.40/0.20 mm minimum through
Planes | In1 GND · In4 +5V · F/B GND pours
Touch | 16.4 mm no-pour region under E1
DRC | 0 violations · 0 unconnected
JLC assembly | 57 placements · 16 BOM groups
Firmware | 16,548 B flash · 2,448 B RAM
Status | build-verified; first article requires electrical bring-up

CODEX KEYBORED · CRYSTAL-LESS USB · PRESS KEYS, SHIP BUGSSHEET 3 / 3

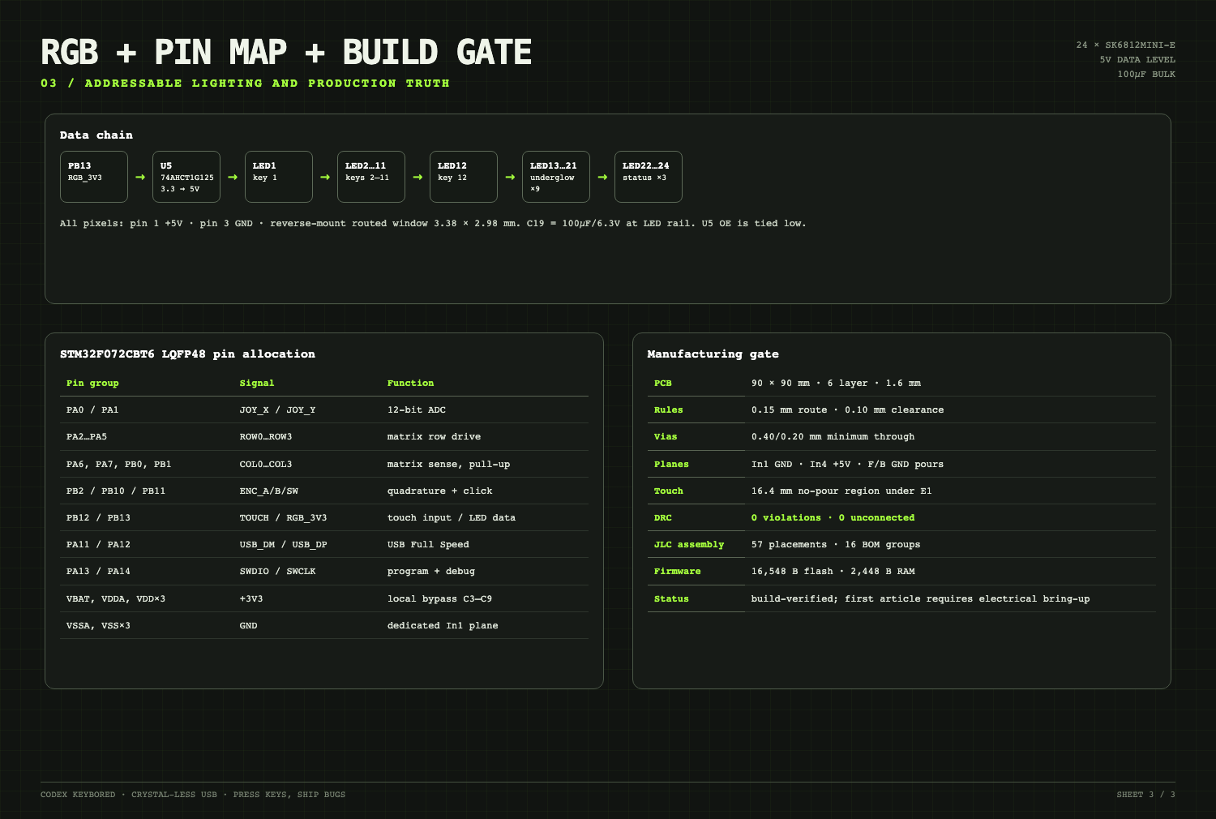
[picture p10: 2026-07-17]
electronics/production/schematic/CODEX_KEYBORED_schematic_3.png

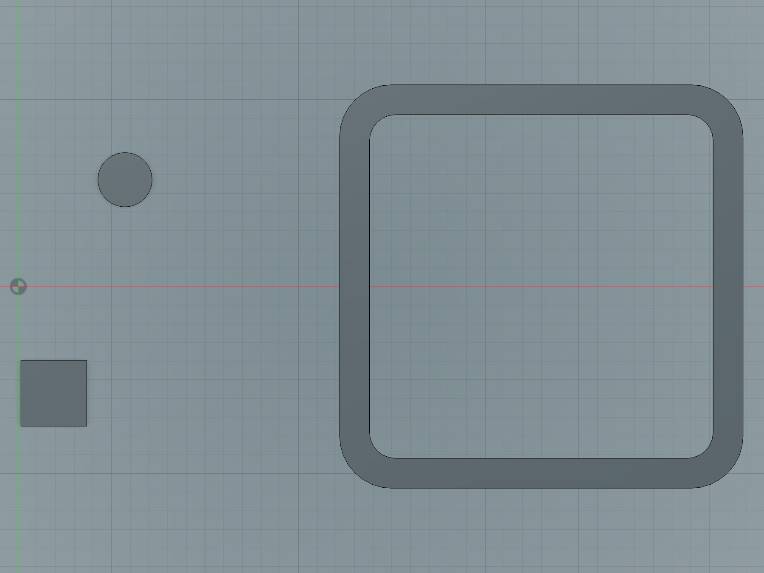
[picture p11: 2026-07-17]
docs/assets/renders/fusion-cm2-003-lightpipe.png

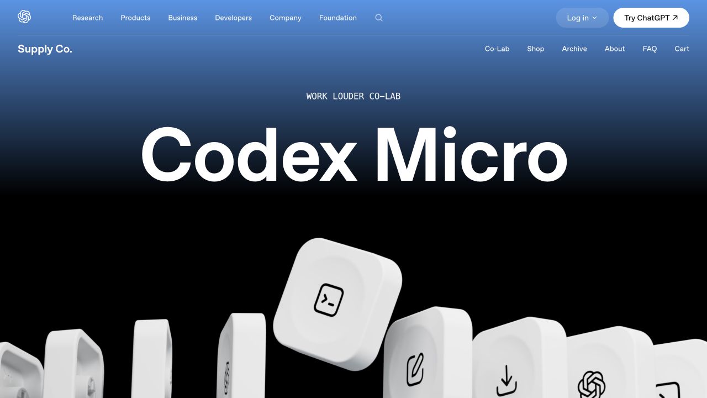
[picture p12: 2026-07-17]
docs/assets/screenshots/openai-codex-micro-official.png

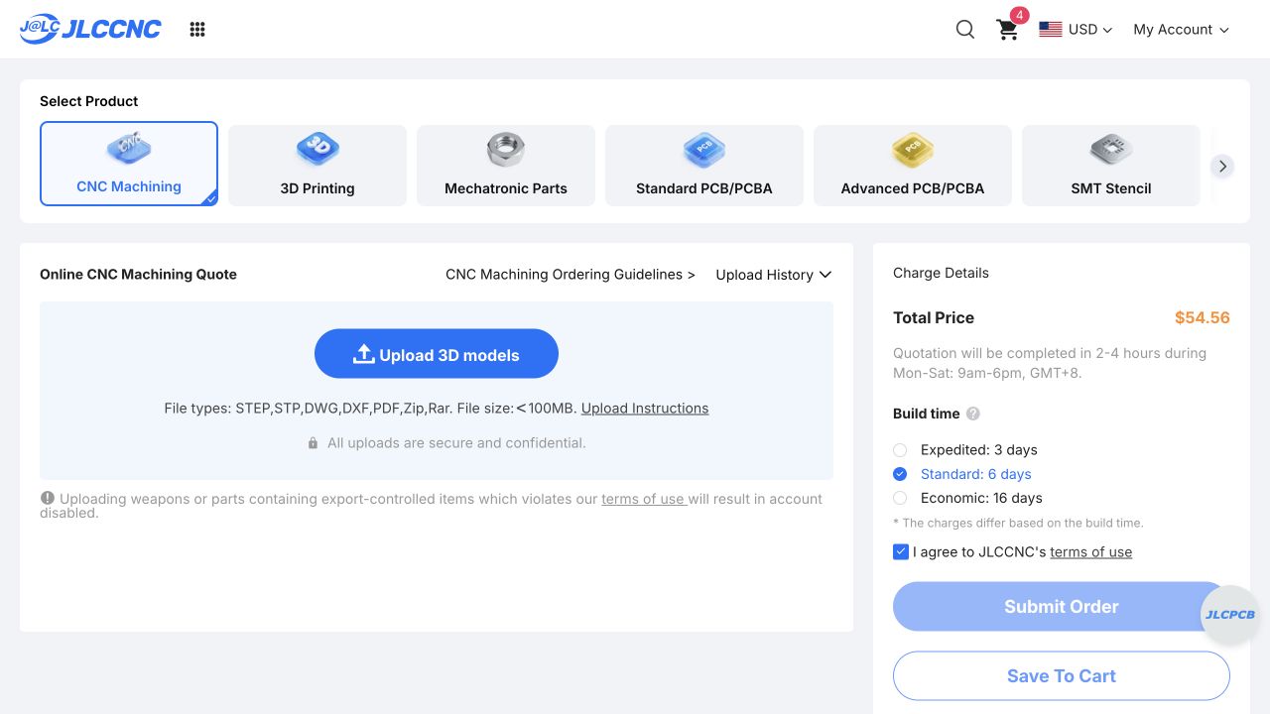
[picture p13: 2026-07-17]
docs/assets/screenshots/jlccnc-angled-wedge-quote.png

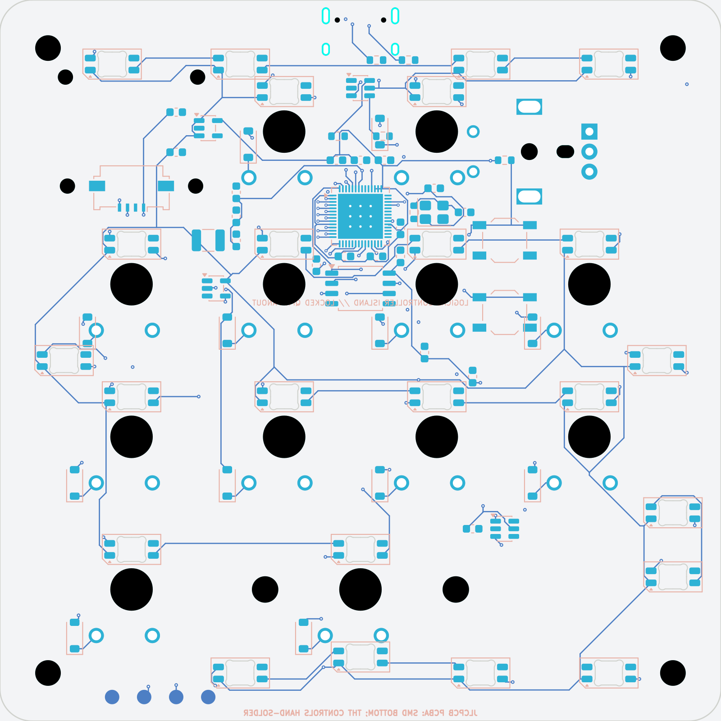
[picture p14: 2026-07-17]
docs/assets/pcb/wired-reva-gerber-bottom.png

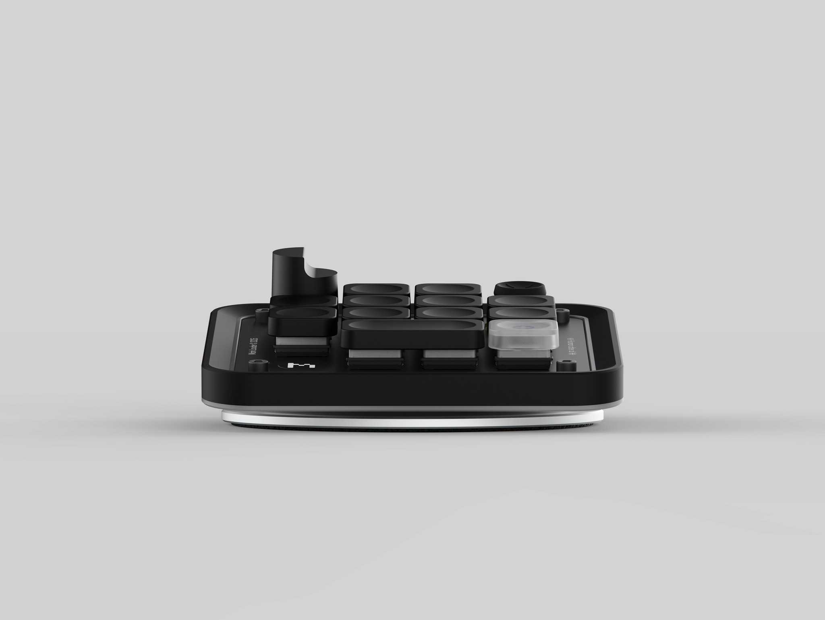
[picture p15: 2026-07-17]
docs/assets/screenshots/worklouder-cm2-angle-3.jpg

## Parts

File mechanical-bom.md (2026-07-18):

# Mechanical BOM and one-off manufacturing plan

Quantities are for one Codex Micro–class device. `Exact` means the part is sold
by Work Louder for Creator Micro 2. `Candidate` means it fits the published
description and measured envelope but still needs confirmation from a PCB photo
or physical sample.

## Buy rather than reproduce

| Item | Qty | Recommended source / specification | Status | Notes |
|---|---:|---|---|---|
| Low-profile switches | 12 + 2 spare | [Work Louder wrk. LP1](https://worklouder.cc/wrk-lp1-switches): MX stem, POM/POK, Gateron low-profile footprint | Exact family | Current pack is 106 pieces for **$59.00**. Choose Clicky or Silent. The encoder push makes the published 13th mechanical input; it is not a keyboard switch. |
| Translucent caps | 1 set | [wrk. MX Pure](https://worklouder.cc/wrk-mx-pure): 12×1U + 1×2U, frosted PC, 19.05 mm pitch | Exact geometry family | Current set is **$19.00**. Provides the correct pass-through-light cap shape. Use six translucent 1U caps; the rest are prototypes/spares. |
| White/icon caps | 5×1U + 1×2U | [wrk. MX Legend](https://worklouder.cc/wrk-mx-legend), or custom-made caps below | Exact interface | The current 58×1U + 1×2U icon set is **$54.00**, but does not reproduce the Codex-specific legends exactly. |
| Dial cap | 1 | [Work Louder wrk. Dial 2](https://worklouder.cc/wrk-dial-2) | Exact accessory | Current price is **$5.98**. Officially compatible with Creator Micro v2. Confirm encoder shaft length before choosing the encoder. |
| Encoder | 1 | Clickable incremental vertical encoder, 6 mm shaft; Bourns PEC11/Alps EC11 class | Candidate | Pinout, detent count, shaft height, and mounting tabs must be measured from an opened CM2. Firmware confirms A, B, and push-switch inputs. |
| Planar joystick | 1 | [Alps Alpine RKJXY100000A](https://tech.alpsalpine.com/e/products/detail/RKJXY100000A/), 19.6×18.1×4.9 mm, 2 kΩ X/Y | High-confidence candidate | The name, dimensions, continuous X/Y action, resin shaft, no center push, and official render geometry all match. The part is discontinued; source surplus or qualify a footprint-compatible OEM clone. |
| Joystick cap | 1 | CM2-004 machined black POM, target Ø14.5 × 7 mm | Quoted prototype | The current rigid cap is a geometry/fit first article. Retention geometry follows the selected joystick and may later be transferred to molded silicone. |
| Top fasteners | 4 | Black ISO 4762 M3 socket-head, provisional M3×10 or M3×12 | Candidate | Render head size matches M3. Final length depends on real standoff/thread depth. |
| Standoffs/inserts | 4 | Ø7 × 8.3 mm envelope, M3 internal thread | Custom/COTS | Turn aluminum/brass standoffs or use commercial M3 female spacers after the lower stack is fixed. |
| Continuous anti-slip ring | 1 | [JLCMC AMFG-P5-A65-65](https://jlcmc.com/product/s/A05/AMFG/o-ring-g-series), JIS B 2401 G-65, black NBR 65 Shore A | Exact purchased part | ID 64.4 ±0.57 mm, section 3.1 ±0.10 mm, nominal OD 70.6 mm. Captured in the machined base groove without adhesive. Live price **$0.1522**; in cart. |
| USB-C receptacle | 1 | HRO TYPE-C-31-M-12, LCSC C165948 | Selected | Exact KiCad footprint and JLCPCB-available part used on wired Rev A. |
| LiPo | 1 | Protected 1S pouch, 1900–2100 mAh, target envelope ≤58×42×6 mm | Candidate | Work Louder publishes 2100 mAh; Framer publishes 1900 mAh. Treat capacity and connector as variant-dependent. |

## Custom keycaps for the Codex look

The least risky path is to buy Work Louder caps for the shape and stem, then add
the artwork. Producing real single-shot PBT at one-off quantity is not economic.

1. **White caps:** start with low-profile MX PBT blanks. Dye-sublimate black
   artwork if the cap material and temperature window are known; otherwise use
   UV print or a thin UV-DTF transfer. Do not laser PBT without test coupons.
2. **Backlit agent caps:** use frosted PC `wrk. MX Pure` caps. Apply an opaque
   top coating, then laser-etch the icon, or leave them translucent and print a
   dark center icon. Test heat and solvent compatibility first.
3. **Fully custom one-off:** SLA-print a tough/clear resin cap master with an MX
   cross, wet-sand and clear-coat it, then cast polyurethane. Print the MX stem
   0.05–0.10 mm undersize only after a calibration coupon; consumer resin
   printers vary too much to assume a nominal press fit.
4. **2U cap:** use two stabilizers at provisional ±11.9 mm from the switch
   center. Do not freeze the stabilizer cutouts until the chosen low-profile
   stabilizer datasheet is selected.

For a private prototype, reproduce only the icons needed for testing. Do not
sell OpenAI/Work Louder branded caps or imply an authorized product.

## CNC housing — original material

### Upper body / captured light diffuser

- Current quoted stock: black POM, minimum 115×115×13 mm.
- Finished envelope: 108×108×10.3 mm, outer R14.
- Inner opening in v0.1: 92×92 mm, R7, leaving an 8 mm nominal wall.
- Finish: no bead blast; polish cosmetic A-surfaces to target Ra ≤0.8 µm.
- Capture the separate 1.5 mm clear cast PMMA light pipe in the 106.4 mm pocket;
  transparent-polish its edges and apply a uniform fine frost to the top face.
- Leave 0.20–0.30 mm total clearance around the 90 mm top PCB/panel until the
  machining process is characterized.

The production threads are in POM: four M3×0.5 PCB bosses and four M2.5×0.45
base bosses. Confirm thread gauges and screw engagement on the first article.

### Bottom wedge

- Stock: 6061-T6 aluminum round/plate, minimum Ø100×14 mm.
- Finished envelope: Ø94 mm, planar top, underside rising from 3.8 mm at the
  front datum to 12.0 mm at the rear datum; nominal tilt 5°.
- Finish quoted at JLC CNC: bead blast + matte black anodize, ISO 2768 medium.
- Four Ø2.8 mm M2.5 clearance holes with Ø5.0 × 1.9 mm counterbores.
- Continuous ring groove: Ø67.5 mm centerline, 3.6 mm wide × 2.2 mm deep.
  The G-65 ring stands 0.9 mm proud nominally; groove-to-counterbore land is
  2.95 mm and the minimum aluminum floor is 1.6 mm.
- Current one-off quote: **$68.31** before shipping; six quoted production days.

### Current JLC CNC one-off estimate

| Machined part | Material / finish | Quote |
|---|---|---:|
| Upper housing | Black POM, polished A-surfaces | $88.97 |
| Angled bottom wedge | 6061, G-65 groove, bead blast + matte black anodize | $68.31 |
| Captured light pipe | Clear cast PMMA, polished edges + frosted top face | $45.70 |
| Joystick cap prototype | Black POM | $19.42 |
| **JLCCNC subtotal** |  | **$222.40** |
| Purchased G-65 ring | JLCMC AMFG-P5-A65-65 | $0.16 |
| **Mechanical merchandise subtotal** | before shipping/tax/duty | **$222.56** |

These are live quote results captured on 2026-07-17, not guaranteed invoice
prices. The groove-base and the other three current parts are saved in the
signed-in cart together with the exact G-65 ring. Superseded flat/no-groove
parts and individual rubber feet were removed; the cart contains exactly four
CNC items and one JLCMC ring for this mechanical revision.

## CNC housing — recommended wood version

Use quarter-sawn hard maple, walnut, or laminated birch rather than unstable
flat-sawn stock. Keep the same 108 mm outline and 92 mm opening, but make the
upper ring 11–12 mm thick and finish-machine both faces after acclimation.

- Add a separate 1.5–2.0 mm frosted acrylic light-pipe/liner below the top PCB;
  wood cannot reproduce the official underglow by itself.
- Seal all faces, especially the inner pocket, with hardwax oil or a thin matte
  polyurethane finish.
- Use brass M3 inserts or separate metal standoffs. Pilot and insert tests belong
  on offcuts from the same stock.
- Allow at least 0.30–0.40 mm total PCB clearance across the grain and keep the
  90 mm panel mechanically located by the four standoffs, not by a tight wood
  pocket.
- A weighted Ø94 aluminum/brass bottom still gives the most faithful desk feel;
  a wood bottom is possible but will be much lighter.

## Dimensions to measure on the first physical sample

1. Exact external width/depth at top and bottom, all corner radii, and total
   height without caps.
2. Top PCB outline/thickness, four screw centers, hole diameter, and screw size.
3. Housing cross-section: inner ledge, standoff heights, bottom-disc step, and
   USB-C/rear-button openings.
4. Dial diameter/height, encoder shaft type and length.
5. Joystick manufacturer marking, pad footprint, cap retention geometry.
6. 2U stabilizer type and spacing.
7. Lower PCB and FFC dimensions; LiPo label, connector, and adhesive locations.

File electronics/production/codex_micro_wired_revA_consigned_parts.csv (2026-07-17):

Item | Manufacturer Part # | Order Qty | Install Qty | Destination | Source | Purpose
Low-profile switch | WRK-LP1 | 106 | 24 on 2 PCBAs | JLCPCB consigned-parts warehouse | https://worklouder.cc/wrk-lp1-switches | 12 switches per board plus factory spares
Planar joystick with stock knob | RKJXY1000006 | 4 | 2 on 2 PCBAs | JLCPCB consigned-parts warehouse | https://akizukidenshi.com/catalog/g/g114675 | In-stock electrical/mechanical sibling of RKJXY100000A
Blank/icon keycap set | WRK-MX-PURE | 1 | 1 finished device | JLCPCB secondary mechanical assembly | https://worklouder.cc/wrk-mx-pure | Fit after electrical test on the PRIMARY unit
Dial cap | WRK-DIAL-2 | 1 | 1 finished device | JLCPCB secondary mechanical assembly | https://worklouder.cc/wrk-dial-2 | Fit after encoder test on the PRIMARY unit

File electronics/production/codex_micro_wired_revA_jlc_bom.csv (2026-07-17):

Comment | Designator | Footprint | LCSC Part # | Manufacturer Part #
10uF 10V X5R 0603 | C1,C2 | C_0603_1608Metric | C19702 | CL10A106KP8NNNC
100nF 16V X7R 0402 | C3,C4,C5,C6,C7 | C_0402_1005Metric | C1525 | CL05B104KO5NNNC
1uF 10V X5R 0402 | C8 | C_0402_1005Metric | C52923 | CL05A105KP5NNNC
4.7uF 10V X5R 0603 | C9 | C_0603_1608Metric | C19666 | CL10A475KO8NNNC
100nF 50V X7R 0603 | C10 | C_0603_1608Metric | C14663 | CC0603KRX7R9BB104
CL32A107MQVNNNE 100uF 6.3V | C19 | C_1210_3225Metric | C49066 | CL32A107MQVNNNE
1N4148W | D1,D2,D3,D4,D5,D6,D7,D8,D9,D10,D11,D12 | D_SOD-123 | C81598 | 1N4148W
TYPE-C-31-M-12 | J1 | USB_C_Receptacle_HRO_TYPE-C-31-M-12 | C165948 | TYPE-C-31-M-12
SK6812MINI-E | LED1,LED2,LED3,LED4,LED5,LED6,LED7,LED8,LED9,LED10,LED11,LED12,LED13,LED14,LED15,LED16,LED17,LED18,LED19,LED20,LED21,LED22,LED23,LED24 | LED_SK6812MINI-E_3.2x2.8mm_P1.5mm_ReverseMount | C5149201 | SK6812MINI-E
5.1k 1% 0603 | R1,R2 | R_0603_1608Metric | C23186 | 0603WAF5101T5E
10k 1% 0603 | R3,R4 | R_0603_1608Metric | C98220 | RC0603FR-0710KL
STM32F072CBT6 128KB crystal-less USB | U1 | LQFP-48_7x7mm_P0.5mm | C81720 | STM32F072CBT6
ME6211C33M5G-N | U3 | SOT-23-5 | C82942 | ME6211C33M5G-N
USBLC6-2SC6 | U4 | SOT-23-6 | C7519 | USBLC6-2SC6
SN74AHCT1G125DBVR | U5 | SOT-23-5 | C7484 | SN74AHCT1G125DBVR
TTP223-BA6-TD | U6 | SOT-23-6 | C42422127 | TTP223-BA6-TD

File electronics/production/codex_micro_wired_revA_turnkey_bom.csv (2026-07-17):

Comment | Designator | Footprint | LCSC Part # | Manufacturer Part #
10uF 10V X5R 0603 | C1,C2 | C_0603_1608Metric | C19702 | CL10A106KP8NNNC
100nF 16V X7R 0402 | C3,C4,C5,C6,C7 | C_0402_1005Metric | C1525 | CL05B104KO5NNNC
1uF 10V X5R 0402 | C8 | C_0402_1005Metric | C52923 | CL05A105KP5NNNC
4.7uF 10V X5R 0603 | C9 | C_0603_1608Metric | C19666 | CL10A475KO8NNNC
100nF 50V X7R 0603 | C10 | C_0603_1608Metric | C14663 | CC0603KRX7R9BB104
CL32A107MQVNNNE 100uF 6.3V | C19 | C_1210_3225Metric | C49066 | CL32A107MQVNNNE
1N4148W | D1,D2,D3,D4,D5,D6,D7,D8,D9,D10,D11,D12 | D_SOD-123 | C81598 | 1N4148W
TYPE-C-31-M-12 | J1 | USB_C_Receptacle_HRO_TYPE-C-31-M-12 | C165948 | TYPE-C-31-M-12
4-position 1.0 mm bottom-contact FFC connector | J2 | Molex_200528-0040_1x04-1MP_P1.00mm_Horizontal |  | 200528-0040
SK6812MINI-E | LED1,LED2,LED3,LED4,LED5,LED6,LED7,LED8,LED9,LED10,LED11,LED12,LED13,LED14,LED15,LED16,LED17,LED18,LED19,LED20,LED21,LED22,LED23,LED24 | LED_SK6812MINI-E_3.2x2.8mm_P1.5mm_ReverseMount | C5149201 | SK6812MINI-E
5.1k 1% 0603 | R1,R2 | R_0603_1608Metric | C23186 | 0603WAF5101T5E
10k 1% 0603 | R3,R4 | R_0603_1608Metric | C98220 | RC0603FR-0710KL
wrk. LP1 low-profile mechanical switch / customer consigned | SW1,SW2,SW3,SW4,SW5,SW6,SW7,SW8,SW9,SW10,SW11,SW12 | Gateron low-profile footprint |  | WRK-LP1
RESET/BOOT0 factory-programming button | SW13,SW14 | SW_SPST_TL3342 | C2886898 | TL3342F160QG
STM32F072CBT6 128KB crystal-less USB | U1 | LQFP-48_7x7mm_P0.5mm | C81720 | STM32F072CBT6
ME6211C33M5G-N | U3 | SOT-23-5 | C82942 | ME6211C33M5G-N
USBLC6-2SC6 | U4 | SOT-23-6 | C7519 | USBLC6-2SC6
SN74AHCT1G125DBVR | U5 | SOT-23-5 | C7484 | SN74AHCT1G125DBVR
TTP223-BA6-TD | U6 | SOT-23-6 | C42422127 | TTP223-BA6-TD
Clickable vertical encoder 18 detents / 9 pulses | ENC1 | RotaryEncoder_Alps_EC11E-Switch_Vertical_H20mm_MountingHoles | C1322538 | EC11E09444A8
Alps ThumbPointer with knob / customer consigned | JOY1 | Alps_RKJXY100000A_MECHANICAL |  | RKJXY1000006

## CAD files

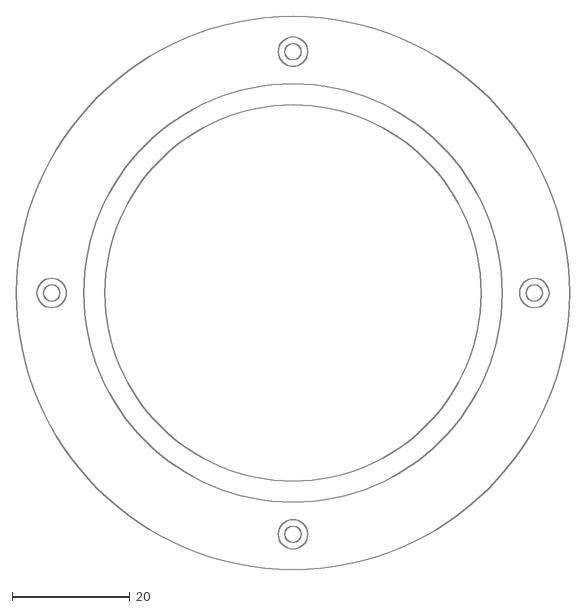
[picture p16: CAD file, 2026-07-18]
cnc/DXF/CM2-002_bottom_weight_profile.dxf
94.0 x 94.0

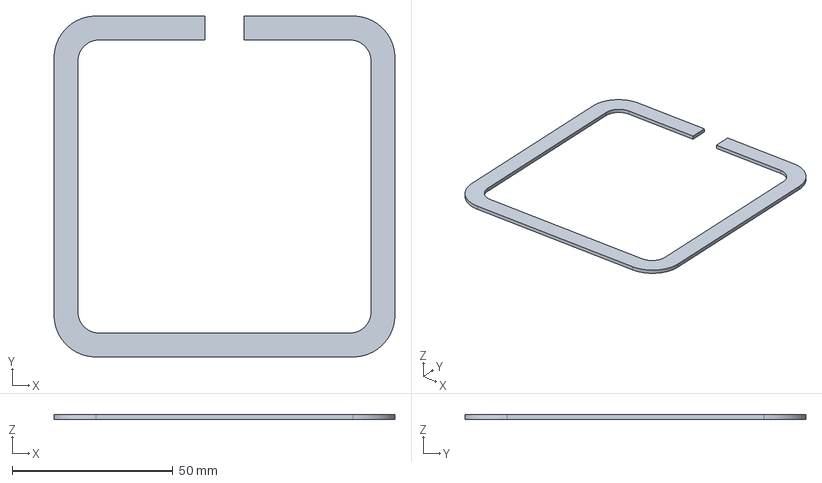
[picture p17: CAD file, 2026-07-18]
cnc/STEP/CM2-003_lightpipe.step
106.1 x 106.1 x 1.50 mm

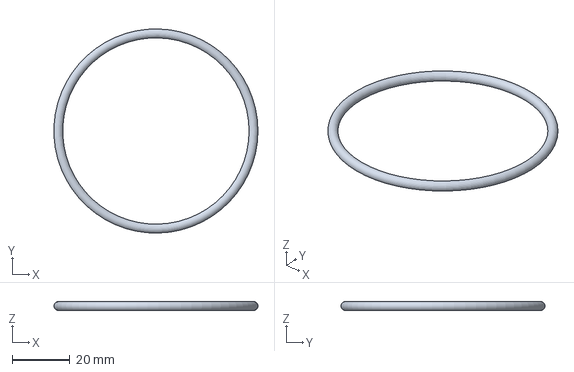
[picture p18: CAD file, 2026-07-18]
cnc/vendor_reference/JLCMC_AMFG-P5-A65-65_G65_oring.step
70.5 x 70.6 x 3.10 mm

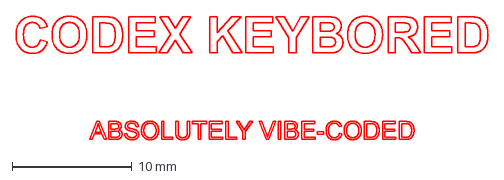
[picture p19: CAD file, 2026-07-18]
cnc/vendor_response/2026-07-18_JLCCNC_laser_marking/CM2-002_LASER_ARTWORK_ONLY_RevB.dxf
39.5 x 10.3 mm

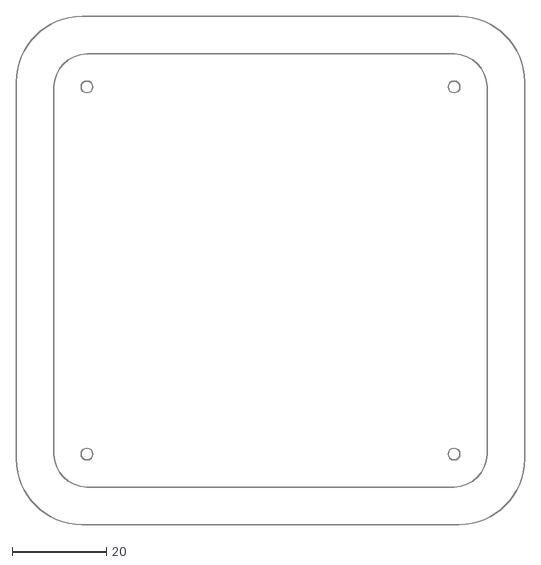
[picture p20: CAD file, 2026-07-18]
cnc/DXF/CM2-001_upper_housing_top_profile.dxf
108.0 x 108.0

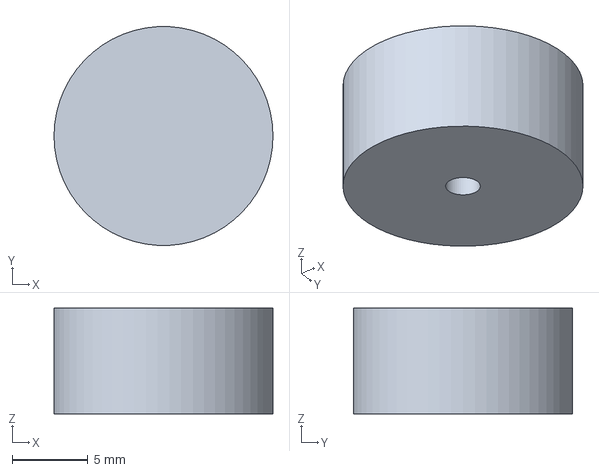
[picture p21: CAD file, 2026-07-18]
cnc/STEP/CM2-004_joystick_cap.step
14.5 x 14.5 x 7.00 mm

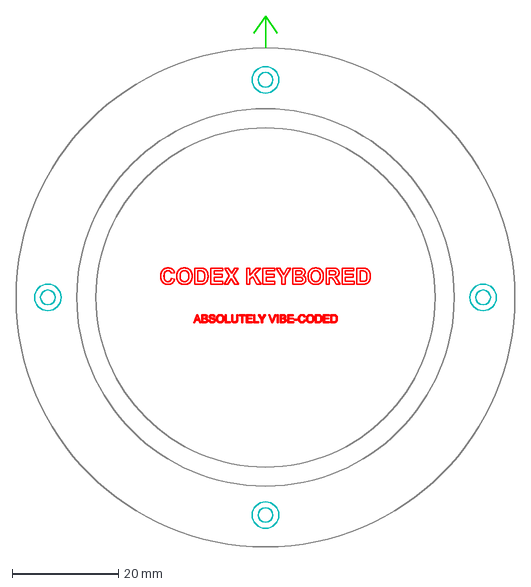
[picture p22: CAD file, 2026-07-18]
cnc/vendor_response/2026-07-18_JLCCNC_laser_marking/CM2-002_LASER_PLACEMENT_REFERENCE_RevB.dxf
94.0 x 100.0 mm

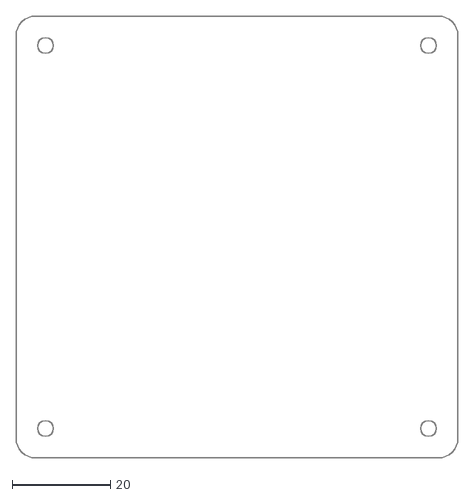
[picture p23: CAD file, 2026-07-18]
cnc/DXF/CM2-006_top_pcb_outline.dxf
90.0 x 90.0

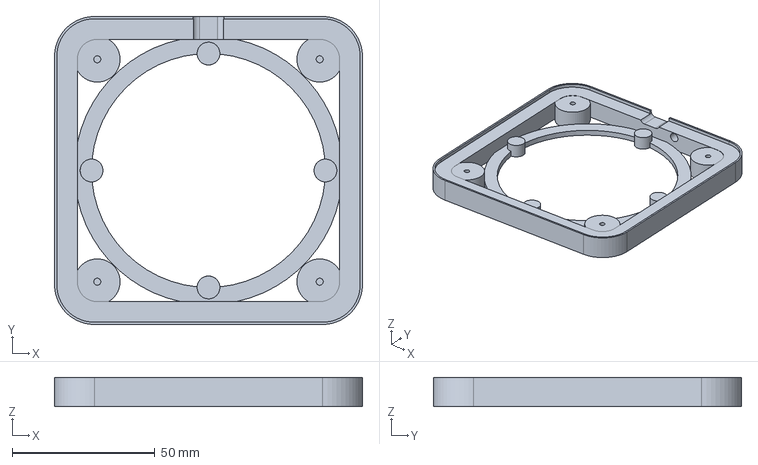
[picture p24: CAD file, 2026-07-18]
cnc/STEP/CM2-001_upper_housing.step
108.0 x 108.0 x 10.3 mm

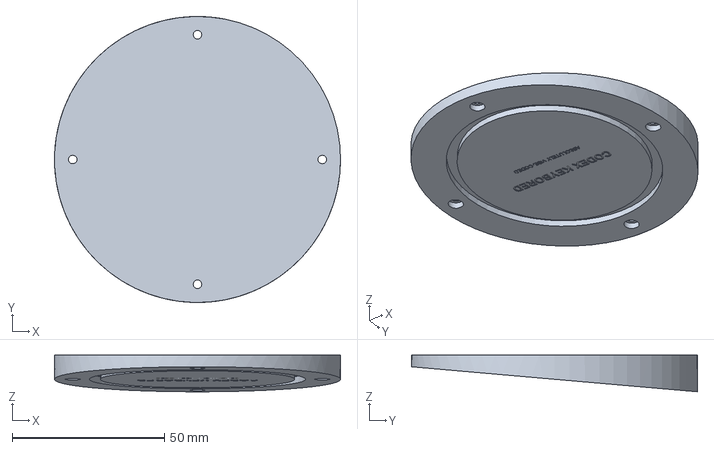
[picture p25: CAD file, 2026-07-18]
cnc/STEP/CM2-002_bottom_weight.step
94.0 x 94.0 x 12.0 mm

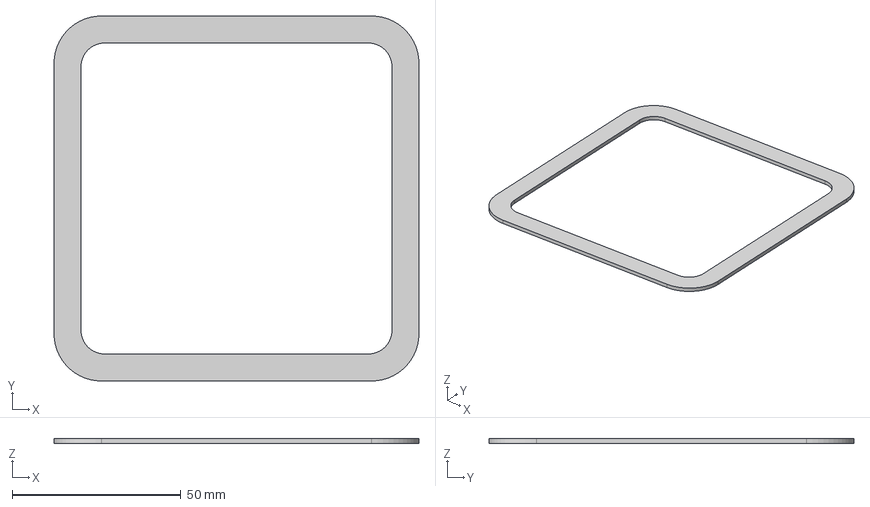
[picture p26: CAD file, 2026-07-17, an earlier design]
cnc/archive/rev_a/CM2-003_optional_lightpipe.step
108.0 x 108.0 x 1.50 mm

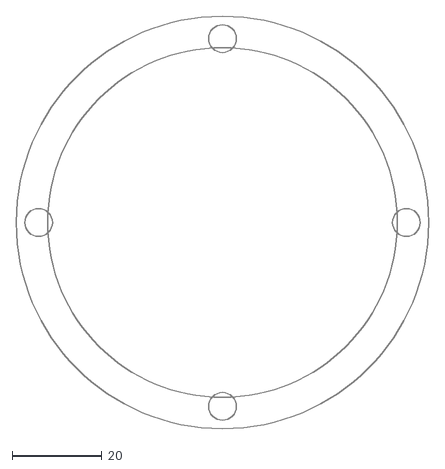
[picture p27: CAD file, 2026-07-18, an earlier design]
cnc/archive/rev_b_tpu_rejected/CM2-005_anti_slip_ring_profile.dxf
92.0 x 92.0

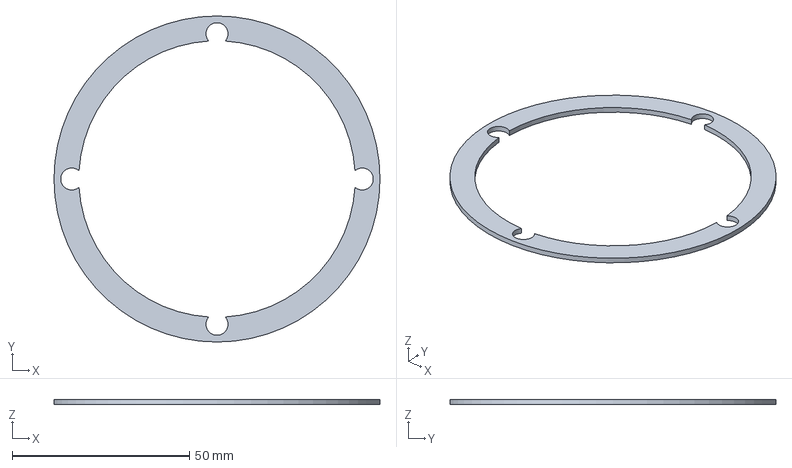
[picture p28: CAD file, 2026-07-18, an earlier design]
cnc/archive/rev_b_tpu_rejected/CM2-005_anti_slip_ring.step
92.0 x 92.0 x 1.50 mm

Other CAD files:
cnc/archive/rev_b_tpu_rejected/CM2-005_anti_slip_ring.stl
fusion/Codex_Micro_RevA.f3d

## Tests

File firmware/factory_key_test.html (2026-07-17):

FACTORY FCT / REV A2

# CodexKeybored

Connect the programmed PCBA over USB, click anywhere on this page, then exercise every key, encoder direction, encoder push, joystick direction, and touch pad. Each expected HID code turns green and stays latched.

0 / 20 controls observed

Reset testFullscreen

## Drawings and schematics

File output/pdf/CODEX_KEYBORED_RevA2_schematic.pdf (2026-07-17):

# CODEX KEYBORED

## J1 · USB-C

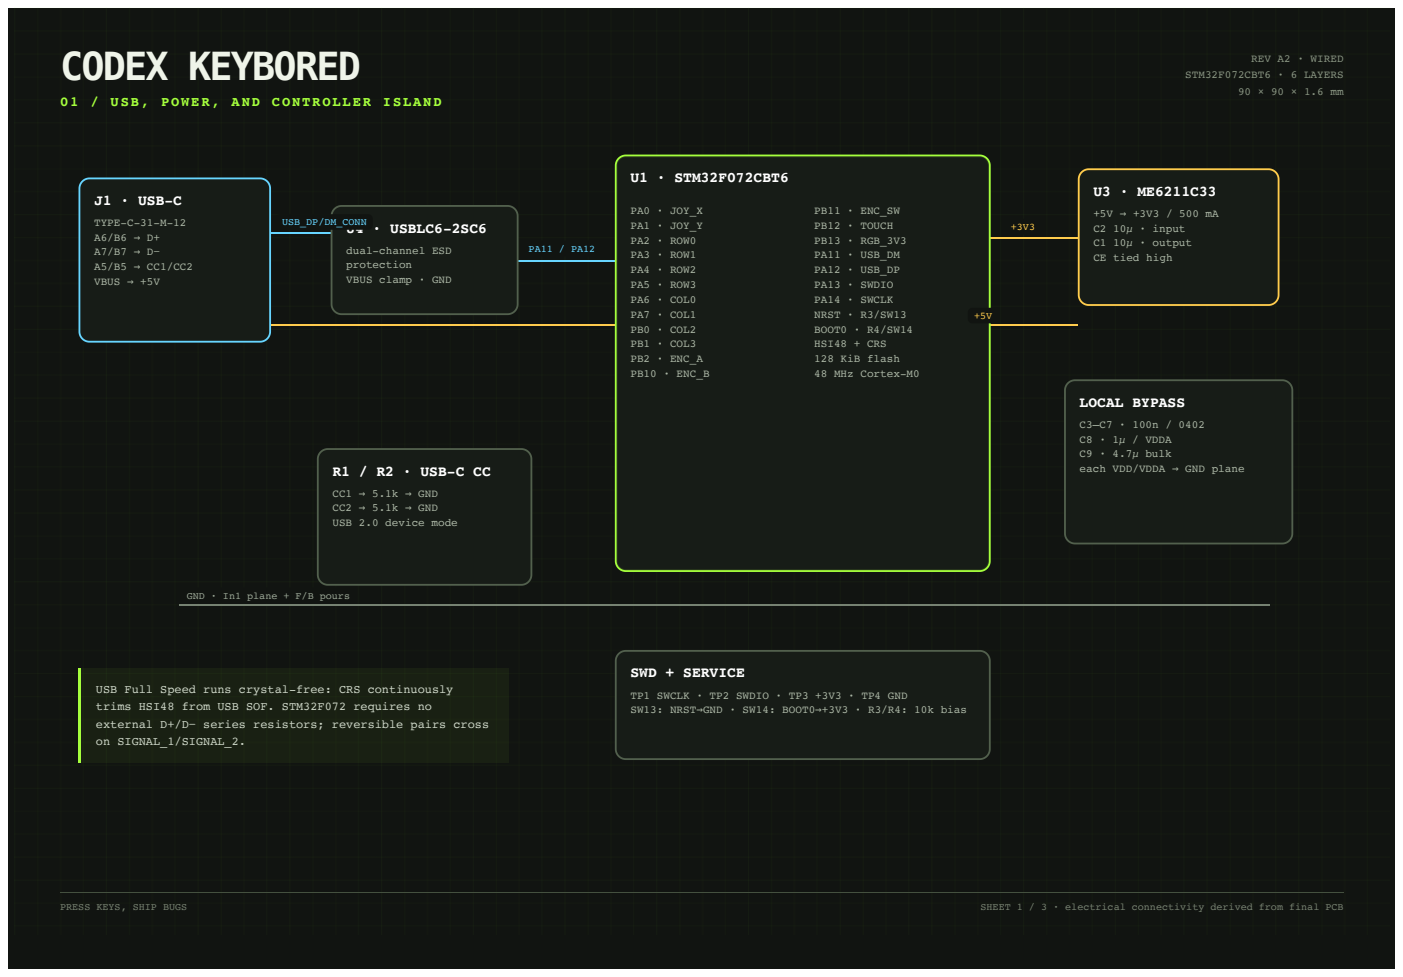
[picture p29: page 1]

01 / USB, POWER, AND CONTROLLER ISLAND

USB Full Speed runs crystal-free: CRS continuously
trims HSI48 from USB SOF. STM32F072 requires no
external D+/D− series resistors; reversible pairs cross
on SIGNAL_1/SIGNAL_2.

# KEY MATRIX + HUMAN INPUT

## ENC1 · CLICKABLE

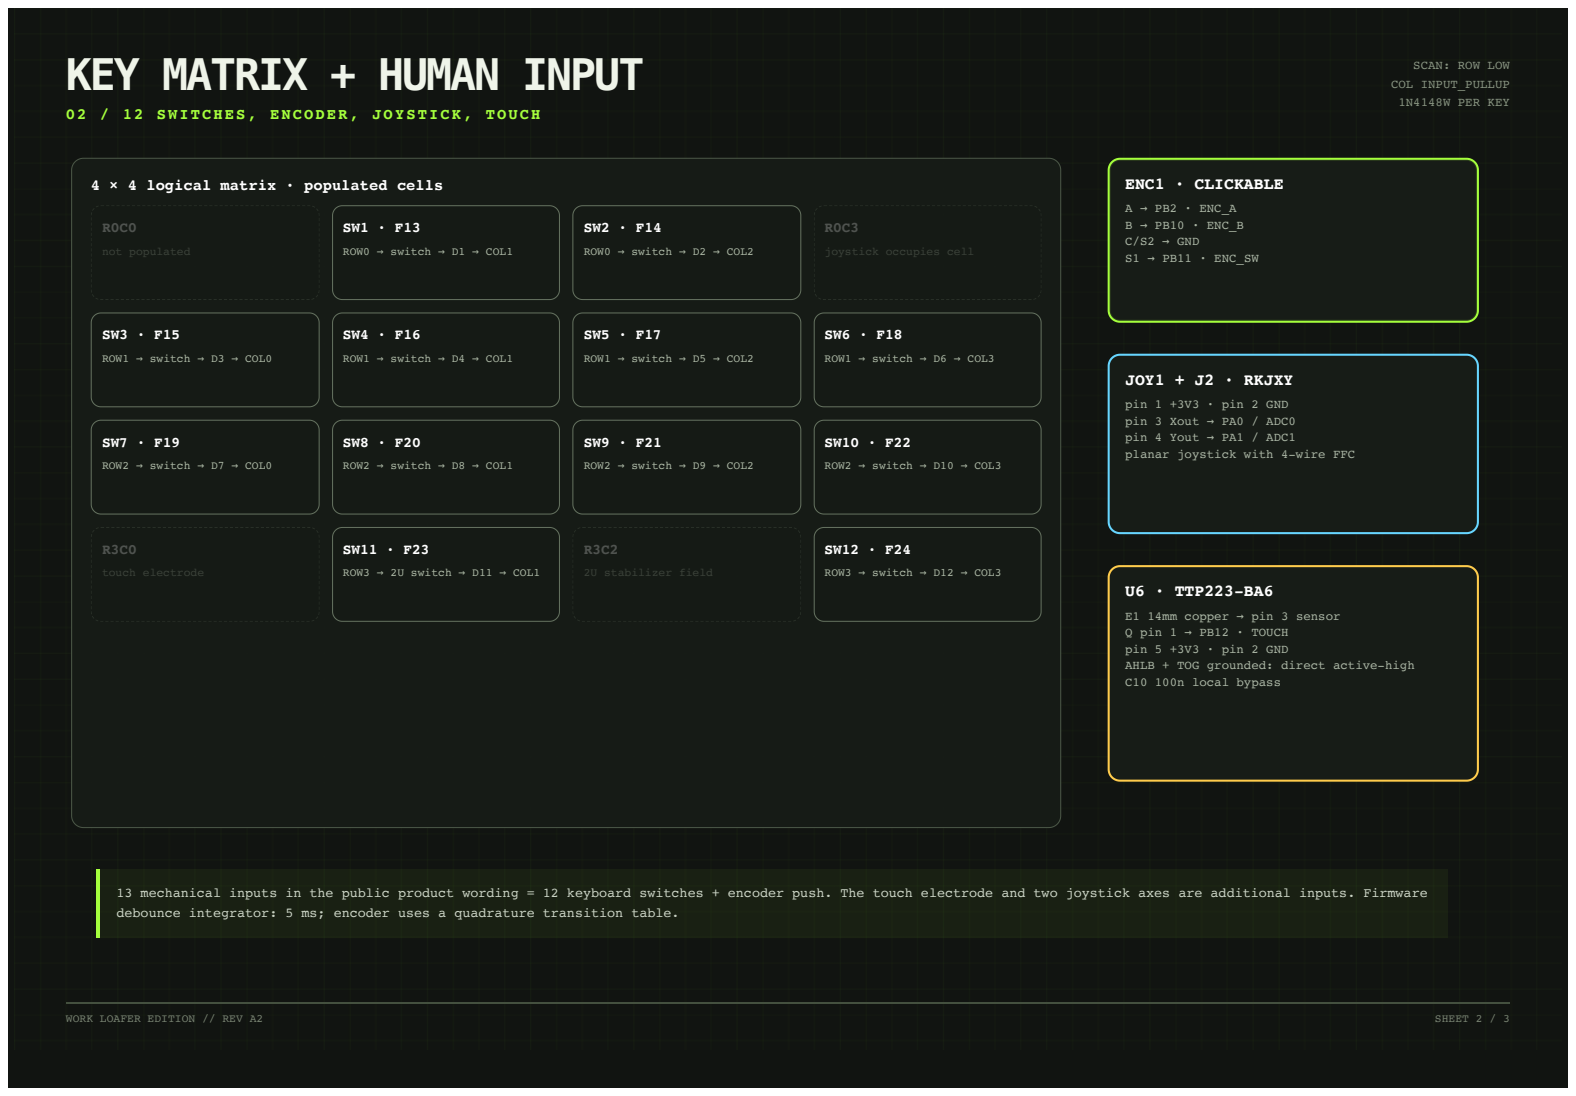
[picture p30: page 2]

02 / 12 SWITCHES, ENCODER, JOYSTICK, TOUCH

4 × 4 logical matrix · populated cells

pin 1 +3V3 · pin 2 GND
pin 3 Xout → PA0 / ADC0
pin 4 Yout → PA1 / ADC1
planar joystick with 4-wire FFC

E1 14mm copper → pin 3 sensor
Q pin 1 → PB12 · TOUCH
pin 5 +3V3 · pin 2 GND
AHLB + TOG grounded: direct active-high
C10 100n local bypass

13 mechanical inputs in the public product wording = 12 keyboard switches + encoder push. The touch electrode and two joystick axes are additional inputs. Firmware
debounce integrator: 5 ms; encoder uses a quadrature transition table.

# RGB + PIN MAP + BUILD GATE

→

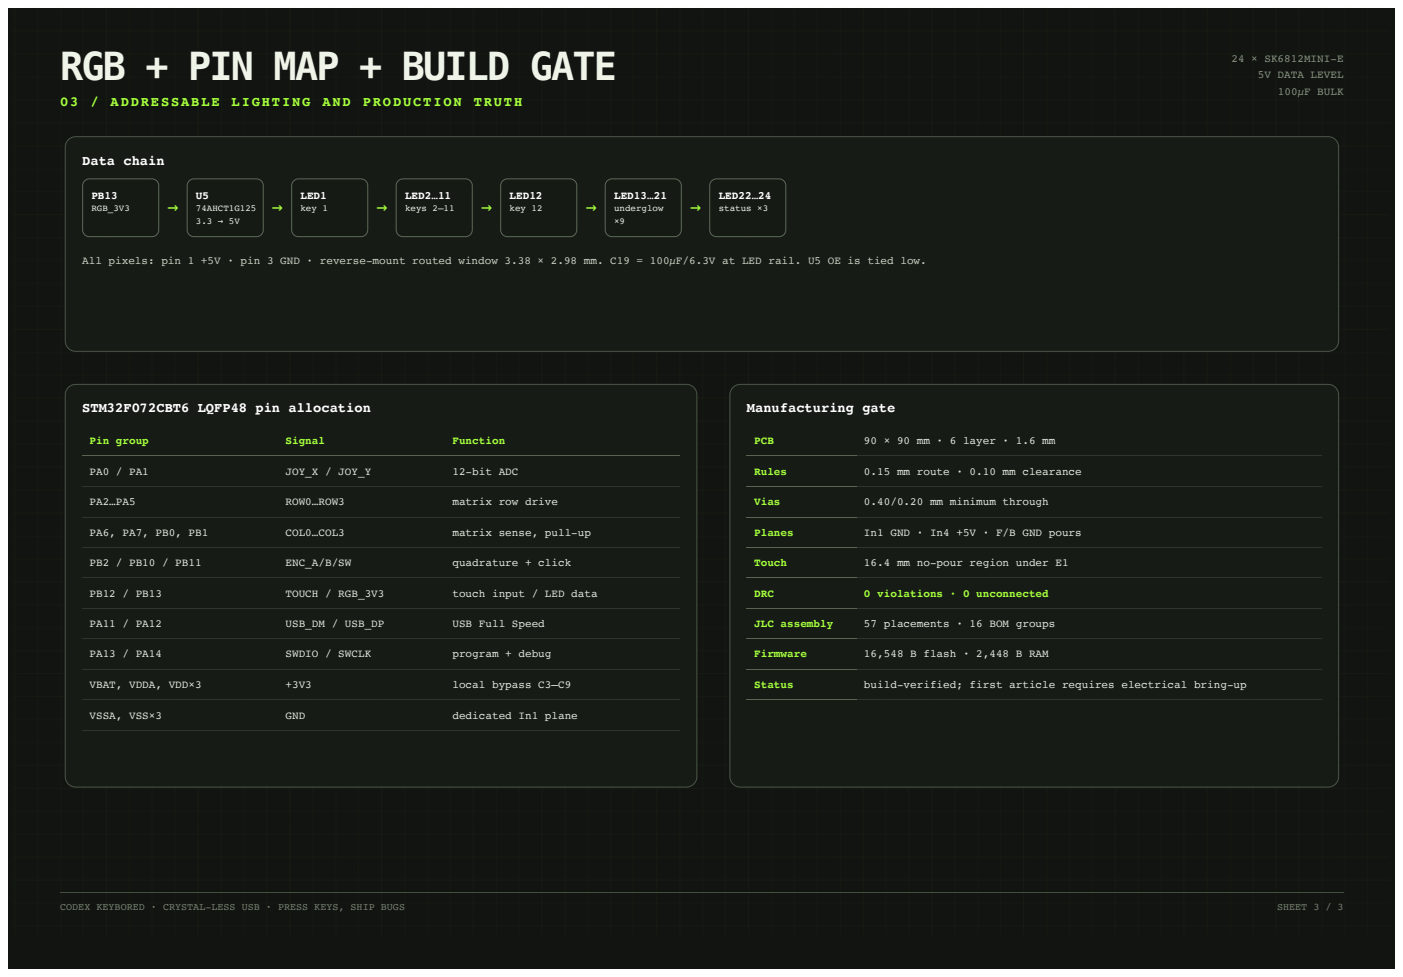
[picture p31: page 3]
24 × SK6812MINI-E; 5V DATA LEVEL; 100µF BULK; Data chain; RGB_3V3; 74AHCT1G125 3.3 → 5V; LED1; key 1; LED2…11; keys 2–11; LED12; key 12; LED13…21; underglow ×9; LED22…24; status ×3; STM32F072CBT6 LQFP48 pin allocation; Pin group; Signal; Function; JOY_X / JOY_Y; 12-bit ADC; ROW0…ROW3; matrix row drive; COL0…COL3; matrix sense, pull-up; ENC_A/B/SW; quadrature + click; TOUCH / RGB_3V3; touch input / LED data; USB_DM / USB_DP; USB Full Speed; SWDIO / SWCLK; program + debug; VBAT, VDDA, VDD×3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

03 / ADDRESSABLE LIGHTING AND PRODUCTION TRUTH

All pixels: pin 1 +5V · pin 3 GND · reverse-mount routed window 3.38 × 2.98 mm. C19 = 100µF/6.3V at LED rail. U5 OE is tied low.

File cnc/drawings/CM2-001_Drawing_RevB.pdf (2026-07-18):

## CODEX KEYBORED / CNC DRAWING PACK

# CM2-001 GLOSS BLACK UPPER HOUSING

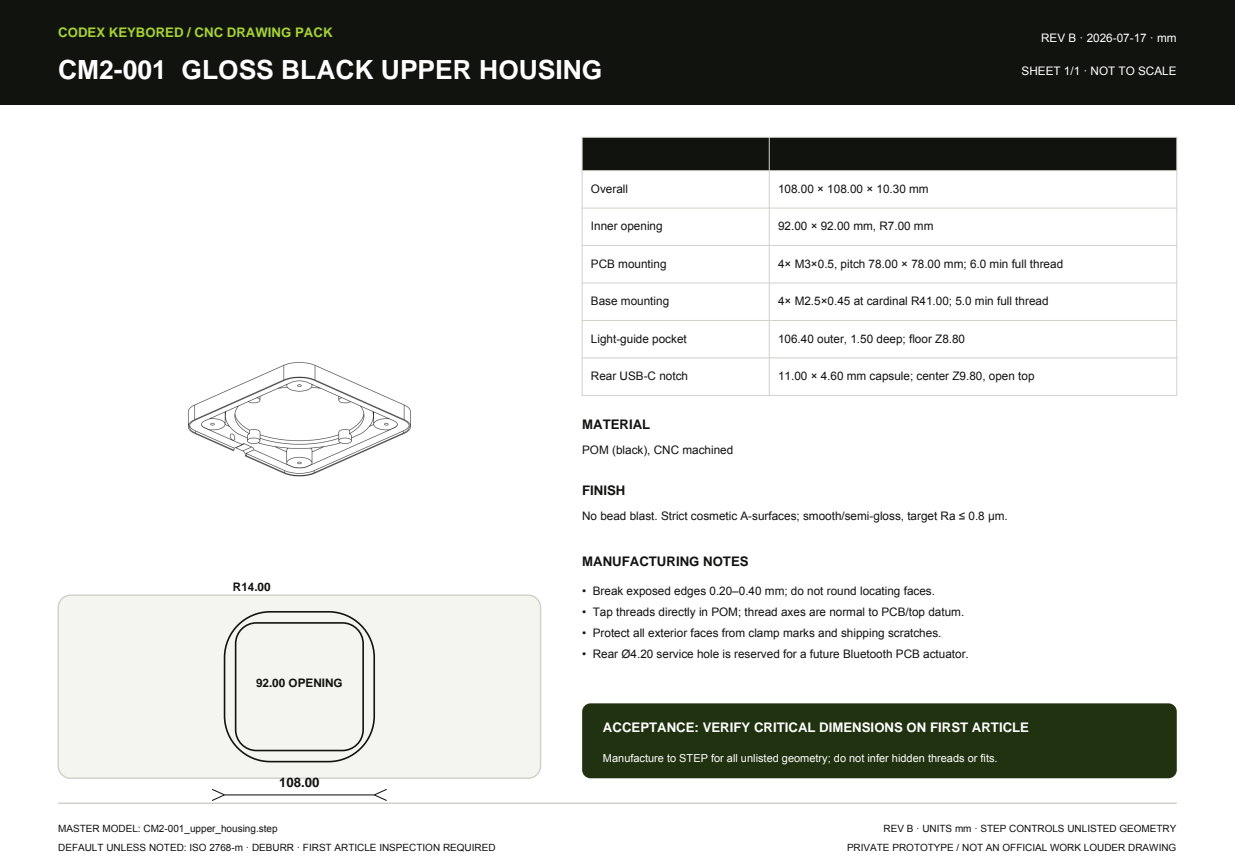
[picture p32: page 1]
REV B · 2026-07-17 · mm; MASTER MODEL: CM2-001_upper_housing.step; REV B · UNITS mm · STEP CONTROLS UNLISTED GEOMETRY; DEFAULT UNLESS NOTED: ISO 2768-m · DEBURR · FIRST ARTICLE INSPECTION REQUIRED; PRIVATE PROTOTYPE / NOT AN OFFICIAL WORK LOUDER DRAWING; 92.00 OPENING; MATERIAL; FINISH; MANUFACTURING NOTES

SHEET 1/1 · NOT TO SCALE

PROPERTY | CONTROLLED REQUIREMENT

Overall | 108.00 × 108.00 × 10.30 mm

Inner opening | 92.00 × 92.00 mm, R7.00 mm

PCB mounting | 4× M3×0.5, pitch 78.00 × 78.00 mm; 6.0 min full thread

Base mounting | 4× M2.5×0.45 at cardinal R41.00; 5.0 min full thread

Light-guide pocket | 106.40 outer, 1.50 deep; floor Z8.80

Rear USB-C notch | 11.00 × 4.60 mm capsule; center Z9.80, open top

POM (black), CNC machined

No bead blast. Strict cosmetic A-surfaces; smooth/semi-gloss, target Ra ≤ 0.8 µm.

• Break exposed edges 0.20–0.40 mm; do not round locating faces.
• Tap threads directly in POM; thread axes are normal to PCB/top datum.
• Protect all exterior faces from clamp marks and shipping scratches.
• Rear Ø4.20 service hole is reserved for a future Bluetooth PCB actuator.

ACCEPTANCE: VERIFY CRITICAL DIMENSIONS ON FIRST ARTICLE

Manufacture to STEP for all unlisted geometry; do not infer hidden threads or fits.

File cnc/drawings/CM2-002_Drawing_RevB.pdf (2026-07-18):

## CODEX KEYBORED / CNC DRAWING PACK

# CM2-002 ANGLED BOTTOM WEIGHT

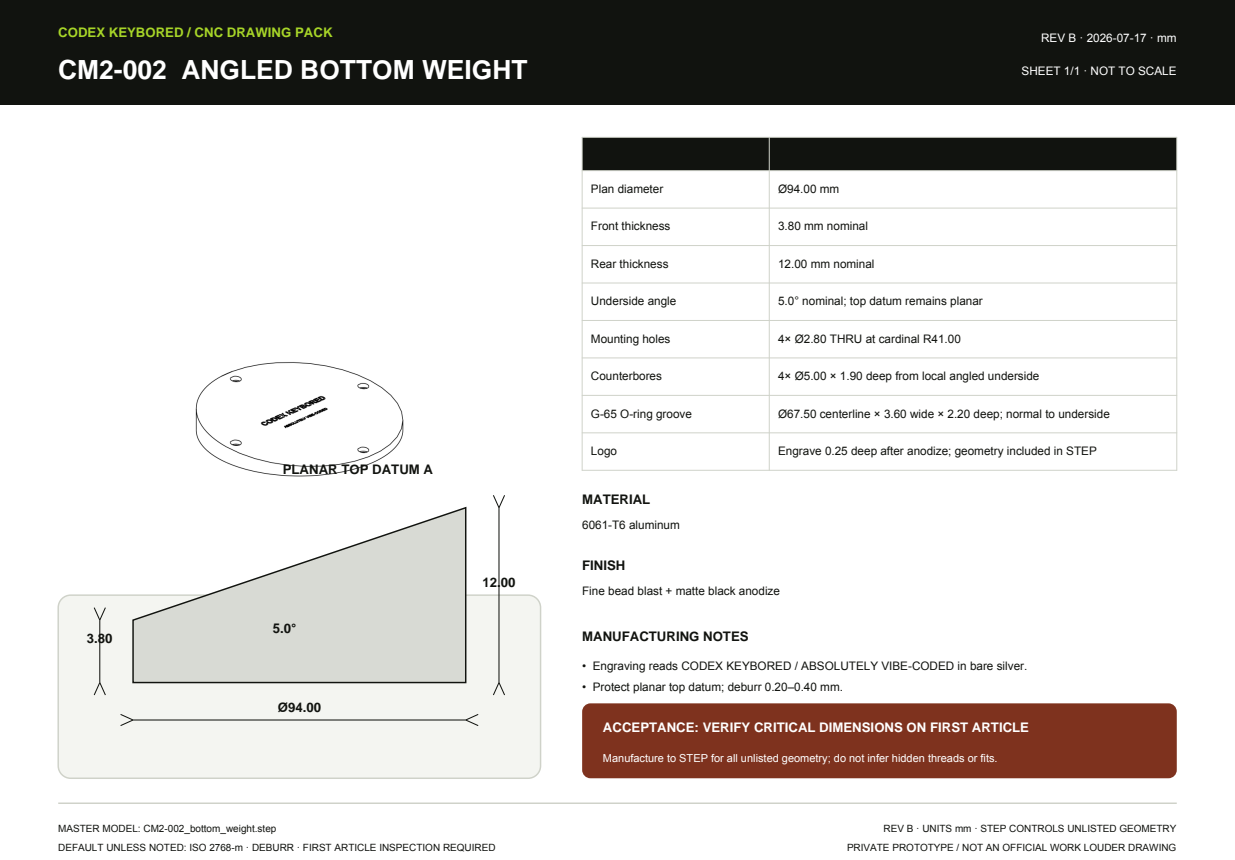
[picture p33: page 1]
REV B · 2026-07-17 · mm; MASTER MODEL: CM2-002_bottom_weight.step; REV B · UNITS mm · STEP CONTROLS UNLISTED GEOMETRY; DEFAULT UNLESS NOTED: ISO 2768-m · DEBURR · FIRST ARTICLE INSPECTION REQUIRED; PRIVATE PROTOTYPE / NOT AN OFFICIAL WORK LOUDER DRAWING; MATERIAL; 6061-T6 aluminum; FINISH; MANUFACTURING NOTES

SHEET 1/1 · NOT TO SCALE

PROPERTY | CONTROLLED REQUIREMENT

Plan diameter | Ø94.00 mm

Front thickness | 3.80 mm nominal

Rear thickness | 12.00 mm nominal

Underside angle | 5.0° nominal; top datum remains planar

Mounting holes | 4× Ø2.80 THRU at cardinal R41.00

Counterbores | 4× Ø5.00 × 1.90 deep from local angled underside

G-65 O-ring groove | Ø67.50 centerline × 3.60 wide × 2.20 deep; normal to underside

Logo | Engrave 0.25 deep after anodize; geometry included in STEP

PLANAR TOP DATUM A

Fine bead blast + matte black anodize

• Engraving reads CODEX KEYBORED / ABSOLUTELY VIBE-CODED in bare silver.
• Protect planar top datum; deburr 0.20–0.40 mm.

ACCEPTANCE: VERIFY CRITICAL DIMENSIONS ON FIRST ARTICLE

Manufacture to STEP for all unlisted geometry; do not infer hidden threads or fits.

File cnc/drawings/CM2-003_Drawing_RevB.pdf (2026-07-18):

## CODEX KEYBORED / CNC DRAWING PACK

# CM2-003 MANDATORY CAPTURED LIGHT GUIDE

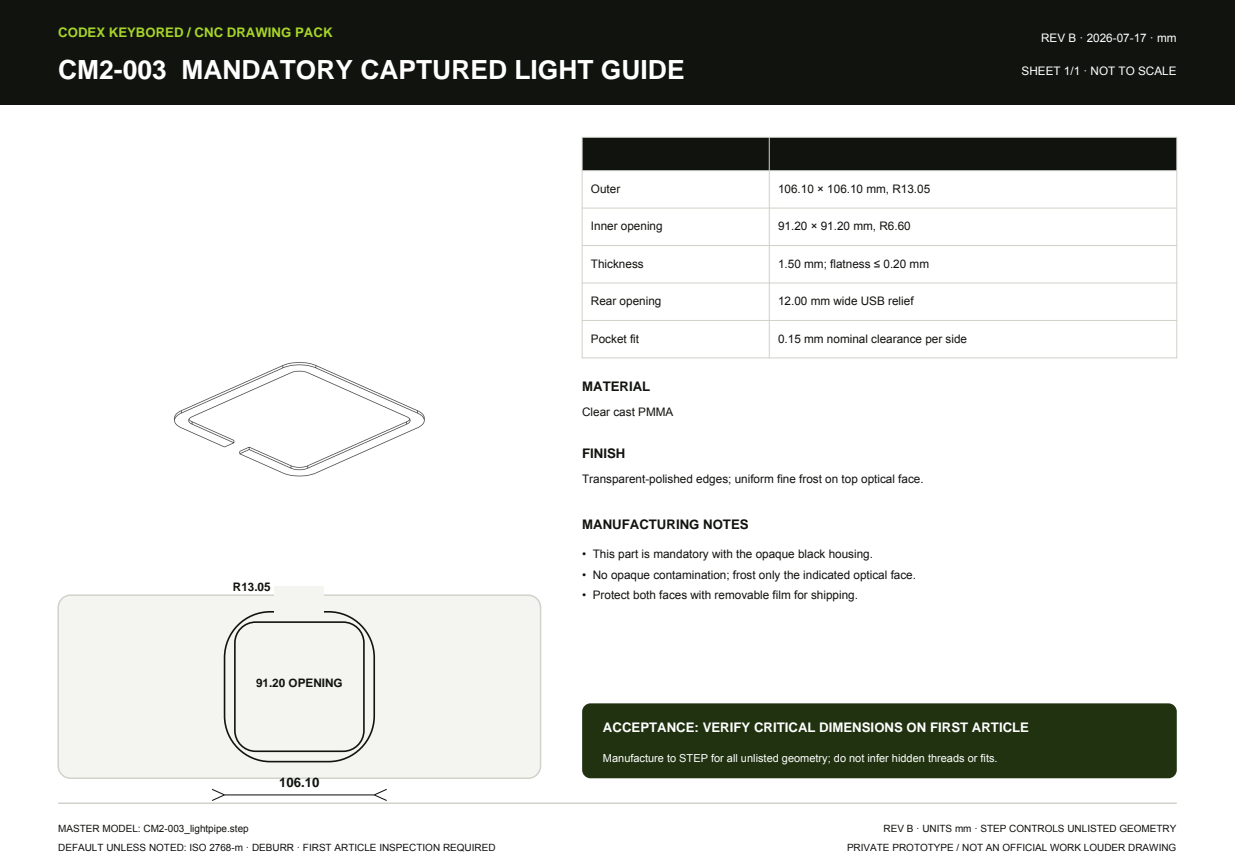
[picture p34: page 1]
REV B · 2026-07-17 · mm; MASTER MODEL: CM2-003_lightpipe.step; REV B · UNITS mm · STEP CONTROLS UNLISTED GEOMETRY; DEFAULT UNLESS NOTED: ISO 2768-m · DEBURR · FIRST ARTICLE INSPECTION REQUIRED; PRIVATE PROTOTYPE / NOT AN OFFICIAL WORK LOUDER DRAWING; 91.20 OPENING; MATERIAL; FINISH; MANUFACTURING NOTES

SHEET 1/1 · NOT TO SCALE

PROPERTY | CONTROLLED REQUIREMENT

Outer | 106.10 × 106.10 mm, R13.05

Inner opening | 91.20 × 91.20 mm, R6.60

Thickness | 1.50 mm; flatness ≤ 0.20 mm

Rear opening | 12.00 mm wide USB relief

Pocket fit | 0.15 mm nominal clearance per side

Clear cast PMMA

Transparent-polished edges; uniform fine frost on top optical face.

• This part is mandatory with the opaque black housing.
• No opaque contamination; frost only the indicated optical face.
• Protect both faces with removable film for shipping.

ACCEPTANCE: VERIFY CRITICAL DIMENSIONS ON FIRST ARTICLE

Manufacture to STEP for all unlisted geometry; do not infer hidden threads or fits.

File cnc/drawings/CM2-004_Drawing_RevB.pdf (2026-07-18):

## CODEX KEYBORED / CNC DRAWING PACK

# CM2-004 JOYSTICK CAP FIT PROTOTYPE

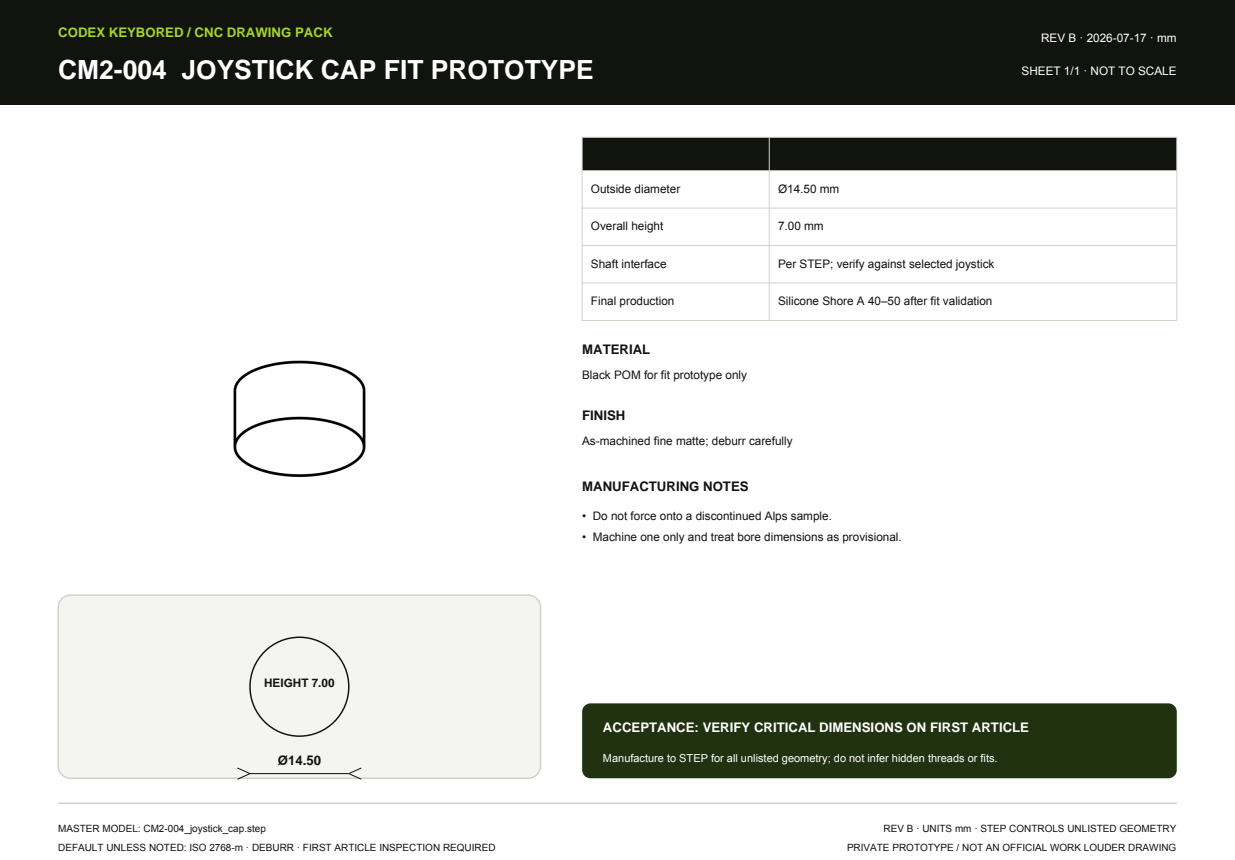
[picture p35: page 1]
REV B · 2026-07-17 · mm; MASTER MODEL: CM2-004_joystick_cap.step; REV B · UNITS mm · STEP CONTROLS UNLISTED GEOMETRY; DEFAULT UNLESS NOTED: ISO 2768-m · DEBURR · FIRST ARTICLE INSPECTION REQUIRED; PRIVATE PROTOTYPE / NOT AN OFFICIAL WORK LOUDER DRAWING; HEIGHT 7.00; MATERIAL; FINISH; MANUFACTURING NOTES

SHEET 1/1 · NOT TO SCALE

PROPERTY | CONTROLLED REQUIREMENT

Outside diameter | Ø14.50 mm

Overall height | 7.00 mm

Shaft interface | Per STEP; verify against selected joystick

Final production | Silicone Shore A 40–50 after fit validation

Black POM for fit prototype only

As-machined fine matte; deburr carefully

• Do not force onto a discontinued Alps sample.
• Machine one only and treat bore dimensions as provisional.

ACCEPTANCE: VERIFY CRITICAL DIMENSIONS ON FIRST ARTICLE

Manufacture to STEP for all unlisted geometry; do not infer hidden threads or fits.

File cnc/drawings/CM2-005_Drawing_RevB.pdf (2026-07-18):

## CODEX KEYBORED / CNC DRAWING PACK

# CM2-005 PURCHASED CONTINUOUS ANTI-SLIP RING

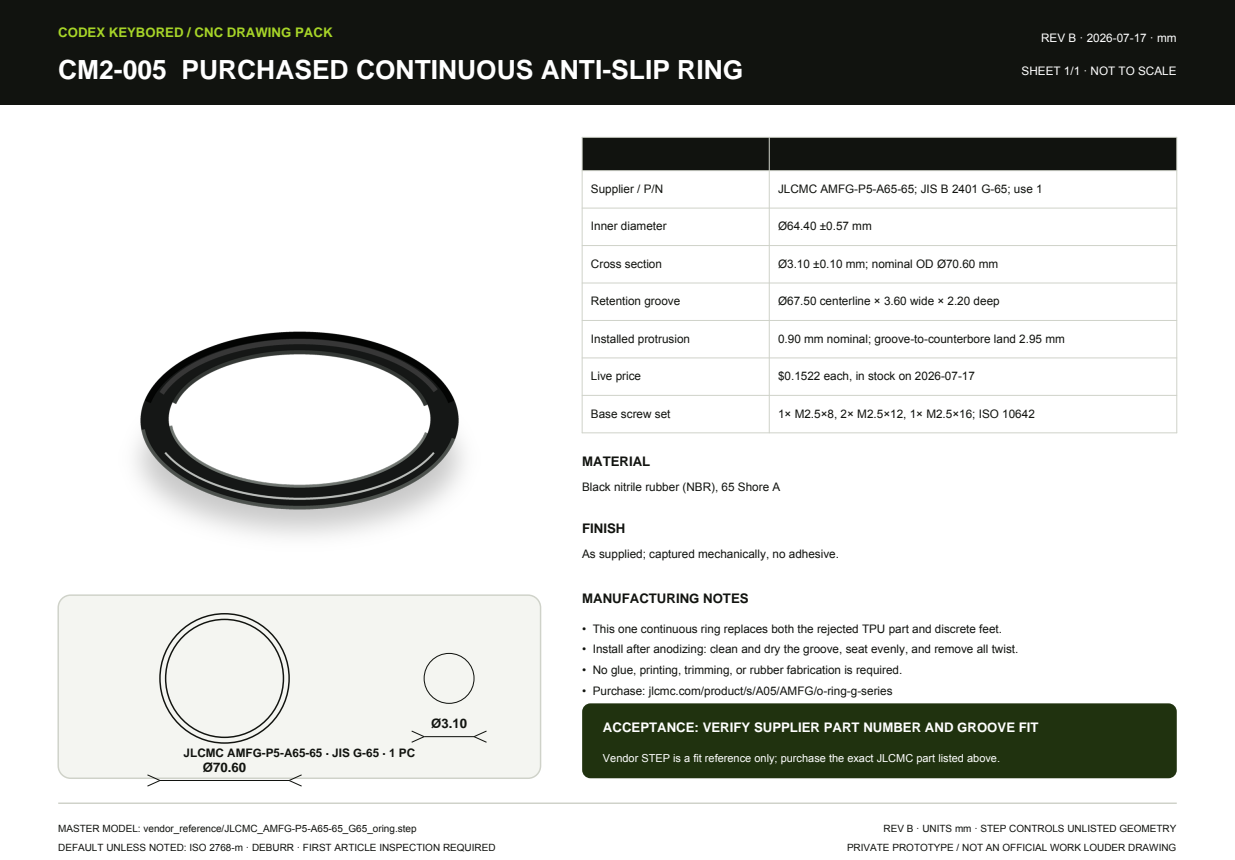
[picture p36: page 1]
REV B · 2026-07-17 · mm; MASTER MODEL: vendor_reference/JLCMC_AMFG-P5-A65-65_G65_oring.step; REV B · UNITS mm · STEP CONTROLS UNLISTED GEOMETRY; DEFAULT UNLESS NOTED: ISO 2768-m · DEBURR · FIRST ARTICLE INSPECTION REQUIRED; PRIVATE PROTOTYPE / NOT AN OFFICIAL WORK LOUDER DRAWING; MATERIAL; FINISH; MANUFACTURING NOTES

SHEET 1/1 · NOT TO SCALE

PROPERTY | CONTROLLED REQUIREMENT

Supplier / P/N | JLCMC AMFG-P5-A65-65; JIS B 2401 G-65; use 1

Inner diameter | Ø64.40 ±0.57 mm

Cross section | Ø3.10 ±0.10 mm; nominal OD Ø70.60 mm

Retention groove | Ø67.50 centerline × 3.60 wide × 2.20 deep

Installed protrusion | 0.90 mm nominal; groove-to-counterbore land 2.95 mm

Live price | $0.1522 each, in stock on 2026-07-17

Base screw set | 1× M2.5×8, 2× M2.5×12, 1× M2.5×16; ISO 10642

Black nitrile rubber (NBR), 65 Shore A

As supplied; captured mechanically, no adhesive.

• This one continuous ring replaces both the rejected TPU part and discrete feet.
• Install after anodizing: clean and dry the groove, seat evenly, and remove all twist.
• No glue, printing, trimming, or rubber fabrication is required.
• Purchase: jlcmc.com/product/s/A05/AMFG/o-ring-g-series

ACCEPTANCE: VERIFY SUPPLIER PART NUMBER AND GROOVE FIT

JLCMC AMFG-P5-A65-65 · JIS G-65 · 1 PC

Vendor STEP is a fit reference only; purchase the exact JLCMC part listed above.

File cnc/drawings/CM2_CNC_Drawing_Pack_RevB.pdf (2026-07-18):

## CODEX KEYBORED / CNC DRAWING PACK

# CM2-001 GLOSS BLACK UPPER HOUSING

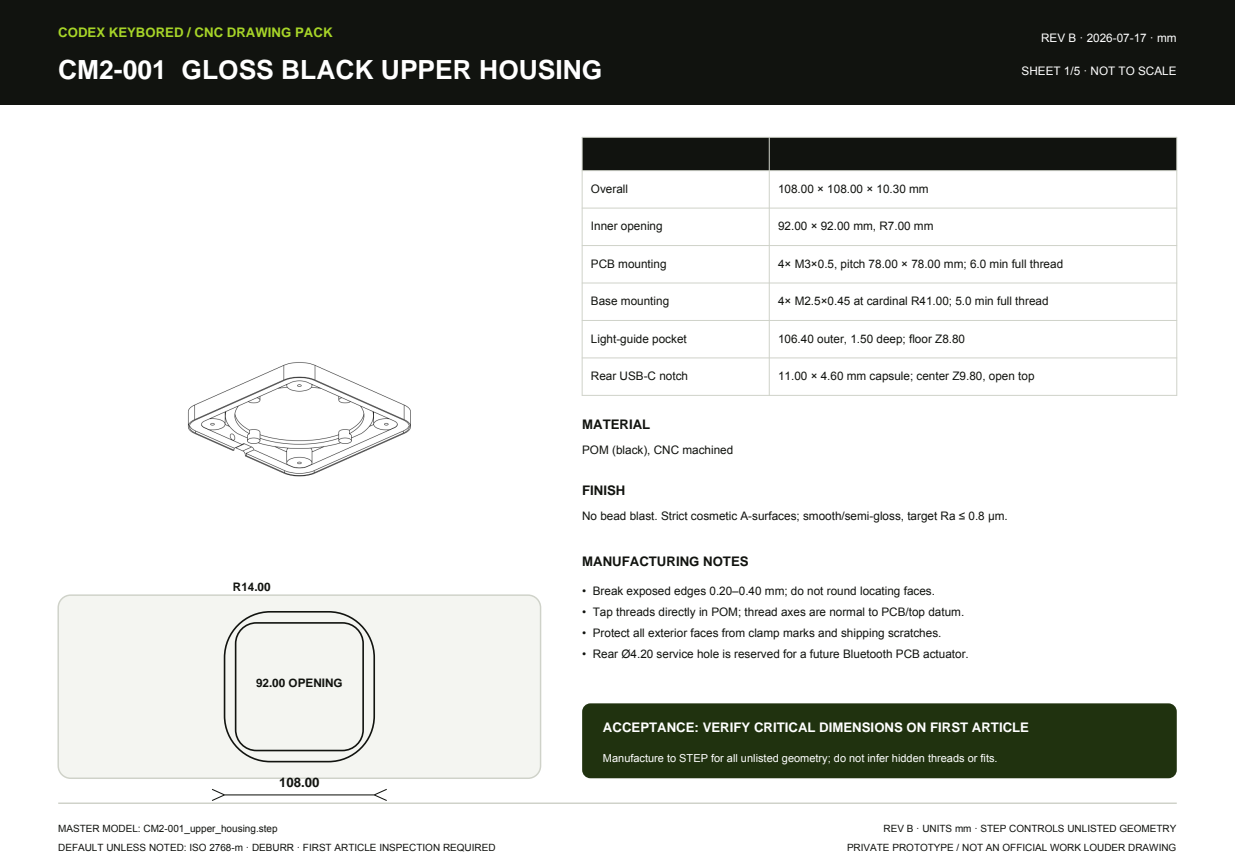
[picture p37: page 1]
REV B · 2026-07-17 · mm; MASTER MODEL: CM2-001_upper_housing.step; REV B · UNITS mm · STEP CONTROLS UNLISTED GEOMETRY; DEFAULT UNLESS NOTED: ISO 2768-m · DEBURR · FIRST ARTICLE INSPECTION REQUIRED; PRIVATE PROTOTYPE / NOT AN OFFICIAL WORK LOUDER DRAWING; 92.00 OPENING; MATERIAL; FINISH; MANUFACTURING NOTES

SHEET 1/5 · NOT TO SCALE

PROPERTY | CONTROLLED REQUIREMENT

Overall | 108.00 × 108.00 × 10.30 mm

Inner opening | 92.00 × 92.00 mm, R7.00 mm

PCB mounting | 4× M3×0.5, pitch 78.00 × 78.00 mm; 6.0 min full thread

Base mounting | 4× M2.5×0.45 at cardinal R41.00; 5.0 min full thread

Light-guide pocket | 106.40 outer, 1.50 deep; floor Z8.80

Rear USB-C notch | 11.00 × 4.60 mm capsule; center Z9.80, open top

POM (black), CNC machined

No bead blast. Strict cosmetic A-surfaces; smooth/semi-gloss, target Ra ≤ 0.8 µm.

• Break exposed edges 0.20–0.40 mm; do not round locating faces.
• Tap threads directly in POM; thread axes are normal to PCB/top datum.
• Protect all exterior faces from clamp marks and shipping scratches.
• Rear Ø4.20 service hole is reserved for a future Bluetooth PCB actuator.

ACCEPTANCE: VERIFY CRITICAL DIMENSIONS ON FIRST ARTICLE

Manufacture to STEP for all unlisted geometry; do not infer hidden threads or fits.

# CM2-002 ANGLED BOTTOM WEIGHT

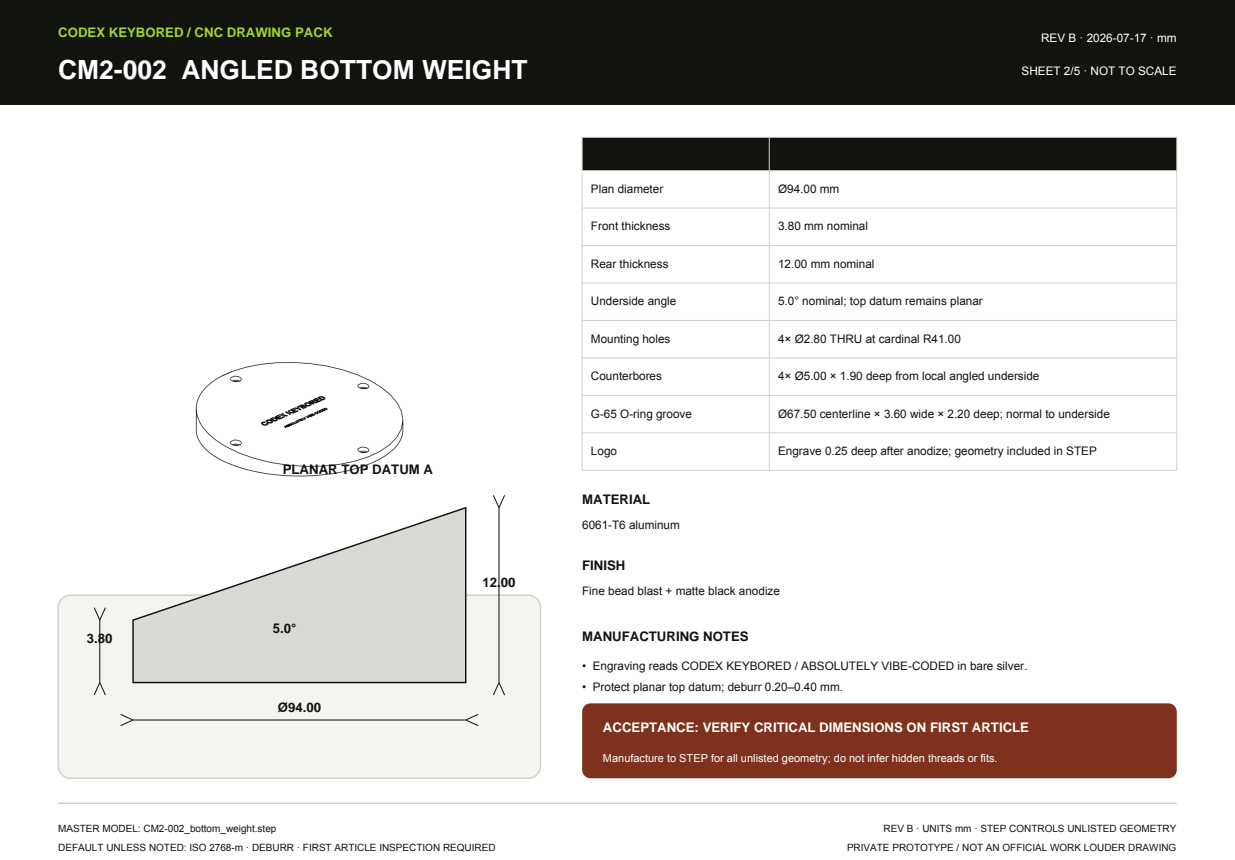
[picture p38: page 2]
MASTER MODEL: CM2-002_bottom_weight.step; REV B · UNITS mm · STEP CONTROLS UNLISTED GEOMETRY; MATERIAL; 6061-T6 aluminum; FINISH; MANUFACTURING NOTES

SHEET 2/5 · NOT TO SCALE

PROPERTY | CONTROLLED REQUIREMENT

Plan diameter | Ø94.00 mm

Front thickness | 3.80 mm nominal

Rear thickness | 12.00 mm nominal

Underside angle | 5.0° nominal; top datum remains planar

Mounting holes | 4× Ø2.80 THRU at cardinal R41.00

Counterbores | 4× Ø5.00 × 1.90 deep from local angled underside

G-65 O-ring groove | Ø67.50 centerline × 3.60 wide × 2.20 deep; normal to underside

Logo | Engrave 0.25 deep after anodize; geometry included in STEP

PLANAR TOP DATUM A

Fine bead blast + matte black anodize

• Engraving reads CODEX KEYBORED / ABSOLUTELY VIBE-CODED in bare silver.
• Protect planar top datum; deburr 0.20–0.40 mm.

ACCEPTANCE: VERIFY CRITICAL DIMENSIONS ON FIRST ARTICLE

Manufacture to STEP for all unlisted geometry; do not infer hidden threads or fits.

# CM2-003 MANDATORY CAPTURED LIGHT GUIDE

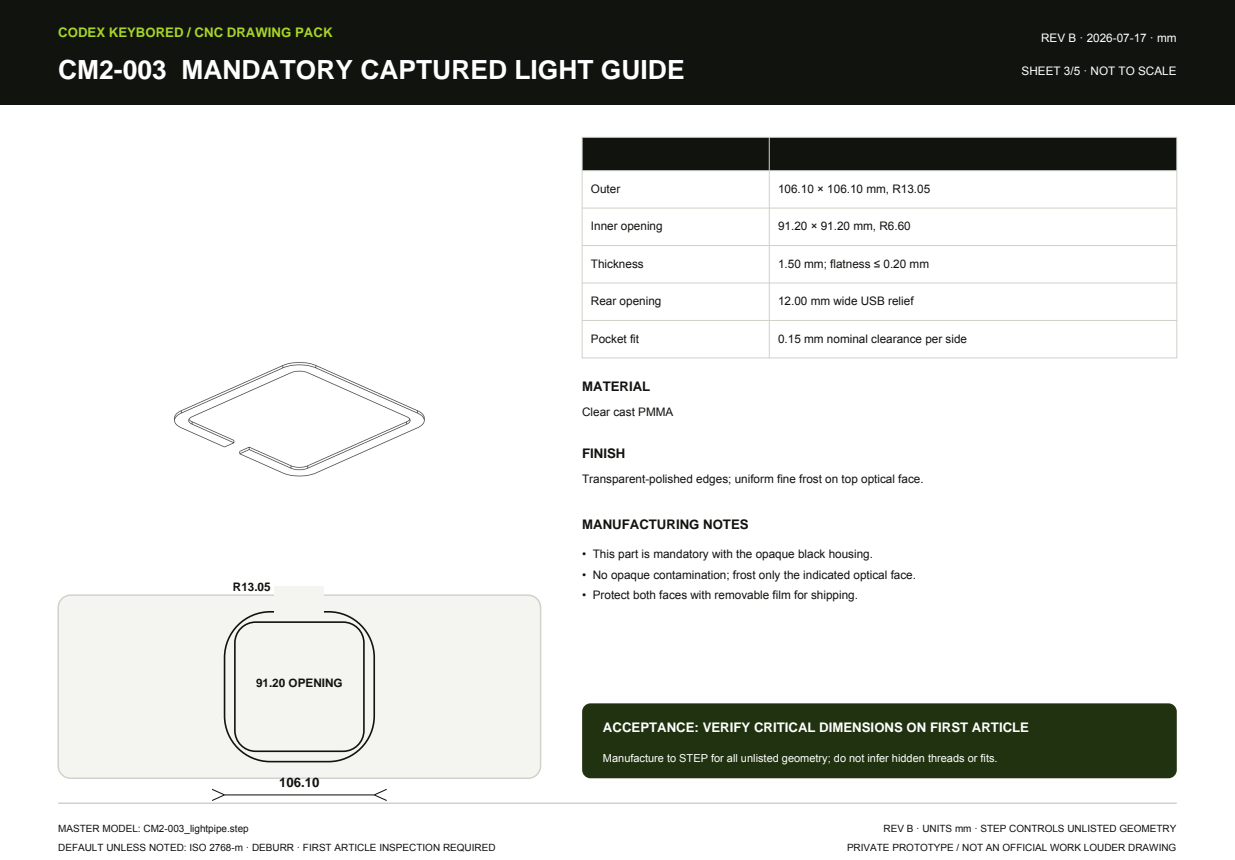
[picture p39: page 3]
MASTER MODEL: CM2-003_lightpipe.step; REV B · UNITS mm · STEP CONTROLS UNLISTED GEOMETRY; 91.20 OPENING; MATERIAL; FINISH; MANUFACTURING NOTES

SHEET 3/5 · NOT TO SCALE

PROPERTY | CONTROLLED REQUIREMENT

Outer | 106.10 × 106.10 mm, R13.05

Inner opening | 91.20 × 91.20 mm, R6.60

Thickness | 1.50 mm; flatness ≤ 0.20 mm

Rear opening | 12.00 mm wide USB relief

Pocket fit | 0.15 mm nominal clearance per side

Clear cast PMMA

Transparent-polished edges; uniform fine frost on top optical face.

• This part is mandatory with the opaque black housing.
• No opaque contamination; frost only the indicated optical face.
• Protect both faces with removable film for shipping.

ACCEPTANCE: VERIFY CRITICAL DIMENSIONS ON FIRST ARTICLE

Manufacture to STEP for all unlisted geometry; do not infer hidden threads or fits.

# CM2-004 JOYSTICK CAP FIT PROTOTYPE

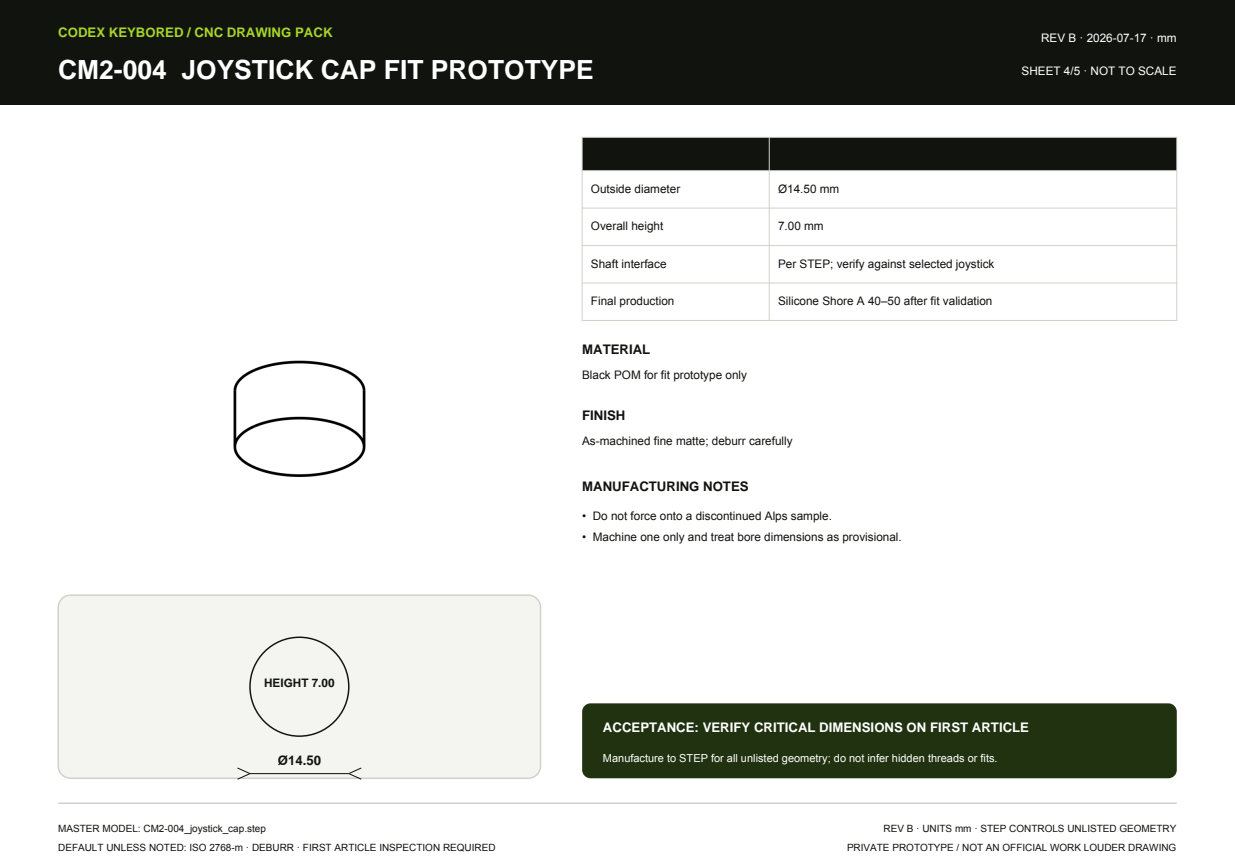
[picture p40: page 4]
MASTER MODEL: CM2-004_joystick_cap.step; REV B · UNITS mm · STEP CONTROLS UNLISTED GEOMETRY; HEIGHT 7.00; MATERIAL; FINISH; MANUFACTURING NOTES

SHEET 4/5 · NOT TO SCALE

PROPERTY | CONTROLLED REQUIREMENT

Outside diameter | Ø14.50 mm

Overall height | 7.00 mm

Shaft interface | Per STEP; verify against selected joystick

Final production | Silicone Shore A 40–50 after fit validation

Black POM for fit prototype only

As-machined fine matte; deburr carefully

• Do not force onto a discontinued Alps sample.
• Machine one only and treat bore dimensions as provisional.

ACCEPTANCE: VERIFY CRITICAL DIMENSIONS ON FIRST ARTICLE

Manufacture to STEP for all unlisted geometry; do not infer hidden threads or fits.
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

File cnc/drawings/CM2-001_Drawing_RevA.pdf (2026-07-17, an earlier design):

## CODEX MICRO / CNC DRAWING PACK

# CM2-001 UPPER HOUSING

REV A · 2026-07-17 · mm; MASTER MODEL: CM2-001_upper_housing.step; DEFAULT UNLESS NOTED: ISO 2768-m · DEBURR · FIRST ARTICLE INSPECTION REQUIRED PRIVATE PROTOTYPE / NOT AN OFFICIAL WORK LOUDER DRAWING; 92.00 OPENING; MATERIAL; FINISH; MANUFACTURING NOTES

SHEET 1/1 · NOT TO SCALE

PROPERTY | CONTROLLED REQUIREMENT

Overall | 108.00 × 108.00 × 10.30 mm

Outer corners | R14.00 mm

Inner opening | 92.00 × 92.00 mm, R7.00 mm

PCB clearance | 0.20–0.30 mm total, validate first article

Cast polycarbonate; alternate cast PMMA or stabilized hardwood

Uniform diffuse matte. No transparent polish required.

• Break exposed edges 0.20–0.40 mm; no sharp edges.

• Do not cut structural threads directly in PMMA.

• Protect cosmetic A-surfaces after bead/frost finish.

ACCEPTANCE: VERIFY CRITICAL DIMENSIONS ON FIRST ARTICLE

Manufacture to STEP for all unlisted geometry; do not infer hidden threads or fits.

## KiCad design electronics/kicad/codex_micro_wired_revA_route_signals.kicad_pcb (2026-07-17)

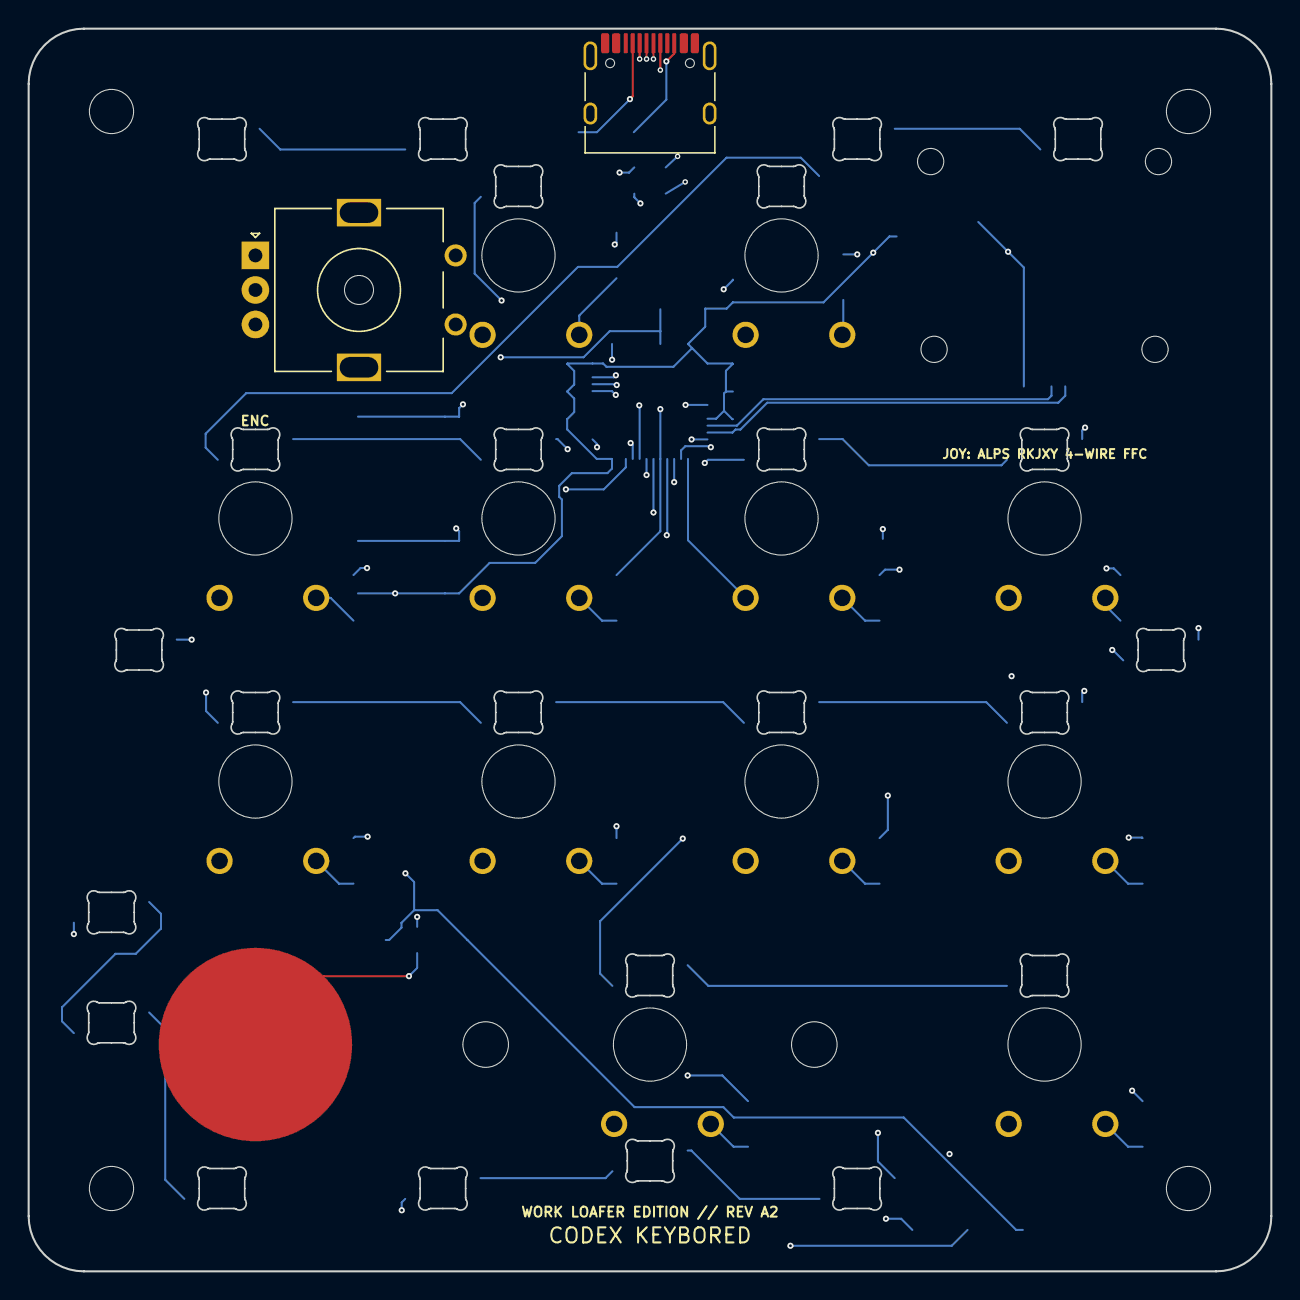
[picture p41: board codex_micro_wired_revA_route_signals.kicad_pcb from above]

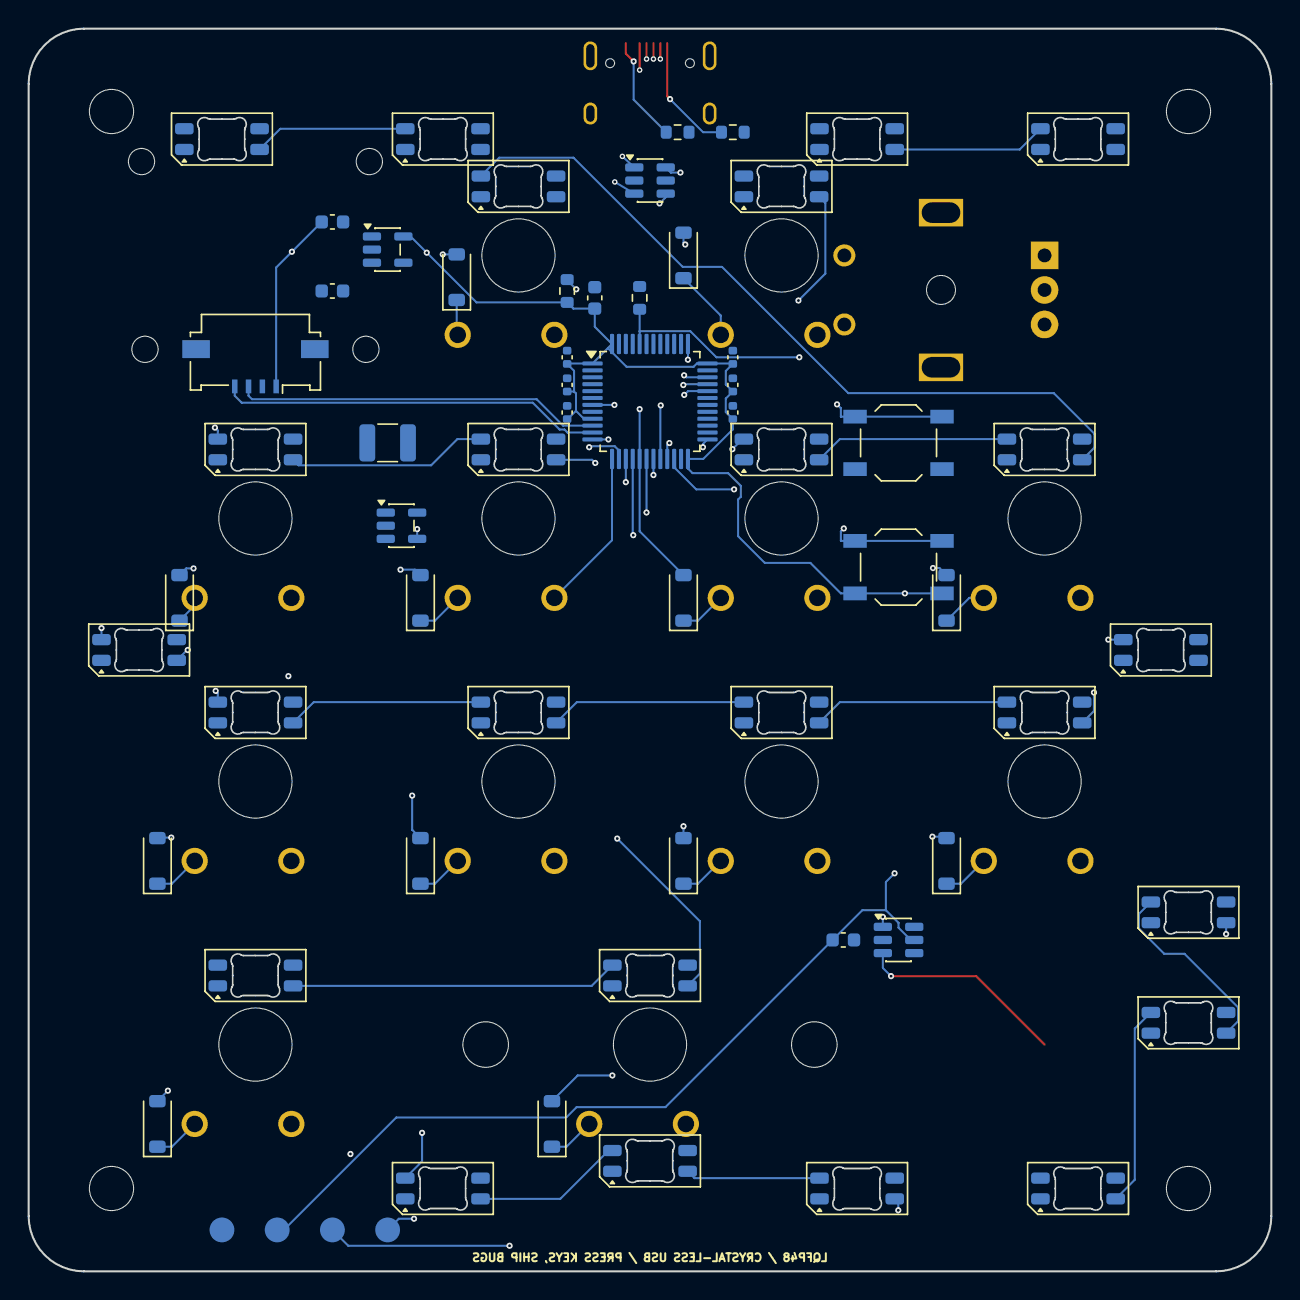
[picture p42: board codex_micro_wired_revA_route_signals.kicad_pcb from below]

Board: 6 copper layers, 90.0 x 90.0 mm, 85 parts (59 on the bottom side), 64 nets.

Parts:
C1, C2: 10uF; C_0603_1608Metric
C3, C4, C5, C6, C7: 100nF_3V3; C_0402_1005Metric
C8: 1uF_VDDA; C_0402_1005Metric
C9: 4.7uF_3V3_BULK; C_0603_1608Metric
C10: 100nF_TOUCH; C_0603_1608Metric
C19: CL32A107MQVNNNE_100uF_6V3; C_1210_3225Metric
D1, D2, D3, D4, D5, D6, D7, D8, D9, D10, D11, D12: 1N4148W; D_SOD-123
E1: CAP_TOUCH_14MM
ENC1: EC11E_VERTICAL_CLICK; RotaryEncoder_Alps_EC11E-Switch_Vertical_H20mm_MountingHoles
H1, H2, H3, H4: MountingHole_M3
HSTAB1, HSTAB2: MountingHole_M3
J1: USB_C_HRO_TYPE-C-31-M-12; USB_C_Receptacle_HRO_TYPE-C-31-M-12
J2: RKJXY_4WIRE_FFC; Molex_200528-0040_1x04-1MP_P1.00mm_Horizontal
JOY1: Alps_RKJXY100000A_MECHANICAL
LED1, LED2, LED3, LED4, LED5, LED6, LED7, LED8, LED9, LED10, LED11, LED12, LED13, LED14, LED15, LED16, LED17, LED18, LED19, LED20, LED21, LED22, LED23, LED24: SK6812MINI-E; LED_SK6812MINI-E_3.2x2.8mm_P1.5mm_ReverseMount
R1: 5.1k_CC1; R_0603_1608Metric
R2: 5.1k_CC2; R_0603_1608Metric
R3: 10k_NRST_PULLUP; R_0603_1608Metric
R4: 10k_BOOT0_PULLDOWN; R_0603_1608Metric
SW1, SW2, SW3, SW4, SW5, SW6, SW7, SW8, SW9, SW10, SW11, SW12: Gateron_KS-33_H10B050NN-Y24
SW13: RESET; SW_SPST_TL3342
SW14: BOOT; SW_SPST_TL3342
TP1: SWCLK
TP2: SWD
TP3: 3V3
TP4: GND
U1: STM32F072CBT6; LQFP-48_7x7mm_P0.5mm
U3: ME6211C33M5G; SOT-23-5
U4: USBLC6-2SC6; SOT-23-6
U5: SN74AHCT1G125DBVR; SOT-23-5
U6: TTP223-BA6-TD; SOT-23-6

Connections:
+3V3: C1.1, C3.1, C4.1, C5.1, C6.1, C7.1, C8.1, C9.1, C10.1, J2.1, R3.1, SW14.2, TP3.1, U1.1, U1.9, U1.24, U1.36, U1.48, U3.5, U6.5
+5V: C2.1, C19.1, J1.A4, J1.A9, J1.B4, J1.B9, LED1.1, LED2.1, LED3.1, LED4.1, LED5.1, LED6.1, LED7.1, LED8.1, LED9.1, LED10.1, LED11.1, LED12.1, LED13.1, LED14.1, LED15.1, LED16.1, LED17.1, LED18.1, LED19.1, LED20.1, LED21.1, LED22.1, LED23.1, LED24.1, U3.1, U3.3, U4.5, U5.5
BOOT0: R4.1, SW14.1, U1.44
COL0: D3.2, D7.2, U1.16
COL1: D1.2, D4.2, D8.2, D11.2, U1.17
COL2: D2.2, D5.2, D9.2, U1.18
COL3: D6.2, D10.2, D12.2, U1.19
ENC_A: ENC1.A, U1.20
ENC_B: ENC1.B, U1.21
ENC_SW: ENC1.S1, U1.22
JOY_X: J2.3, U1.10
JOY_Y: J2.4, U1.11
LED_D1: LED1.2, LED2.4
LED_D2: LED2.2, LED3.4
LED_D3: LED3.2, LED4.4
LED_D4: LED4.2, LED5.4
LED_D5: LED5.2, LED6.4
LED_D6: LED6.2, LED7.4
LED_D7: LED7.2, LED8.4
LED_D8: LED8.2, LED9.4
LED_D9: LED9.2, LED10.4
LED_D10: LED10.2, LED11.4
LED_D11: LED11.2, LED12.4
LED_D12: LED12.2, LED13.4
LED_D13: LED13.2, LED14.4
LED_D14: LED14.2, LED15.4
LED_D15: LED15.2, LED16.4
LED_D16: LED16.2, LED17.4
LED_D17: LED17.2, LED18.4
LED_D18: LED18.2, LED19.4
LED_D19: LED19.2, LED20.4
LED_D20: LED20.2, LED21.4
LED_D21: LED21.2, LED22.4
LED_D22: LED22.2, LED23.4
LED_D23: LED23.2, LED24.4
NRST: R3.2, SW13.1, U1.7
RGB_3V3: U1.26, U5.2
RGB_5V: LED1.4, U5.4
ROW0: SW1.1, SW2.1, U1.12
ROW1: SW3.1, SW4.1, SW5.1, SW6.1, U1.13
ROW2: SW7.1, SW8.1, SW9.1, SW10.1, U1.14
ROW3: SW11.1, SW12.1, U1.15
SW1_D: D1.1, SW1.2
SW2_D: D2.1, SW2.2
SW3_D: D3.1, SW3.2
SW4_D: D4.1, SW4.2
SW5_D: D5.1, SW5.2
SW6_D: D6.1, SW6.2
SW7_D: D7.1, SW7.2
SW8_D: D8.1, SW8.2
SW9_D: D9.1, SW9.2
SW10_D: D10.1, SW10.2
SW11_D: D11.1, SW11.2
SW12_D: D12.1, SW12.2
SWCLK: TP1.1, U1.37
SWD: TP2.1, U1.34
TOUCH: U1.25, U6.1
TOUCH_ELECTRODE: E1.1, U6.3
USB_CC1: J1.A5, R1.1
USB_CC2: J1.B5, R2.1
USB_DM_CONN: J1.A7, J1.B7, U4.3
USB_DM_PROT: U1.32, U4.4
USB_DP_CONN: J1.A6, J1.B6, U4.1
USB_DP_PROT: U1.33, U4.6

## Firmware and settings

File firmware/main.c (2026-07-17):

#include <stdbool.h>
#include <stdint.h>
#include <string.h>

#include "bsp/board.h"
#include "hardware/adc.h"
#include "hardware/pio.h"
#include "pico/stdlib.h"
#include "tusb.h"
#include "class/hid/hid_device.h"
#include "ws2812.pio.h"

static const uint8_t row_gpio[4] = {0, 1, 2, 3};
static const uint8_t col_gpio[4] = {4, 5, 6, 7};
static const uint8_t encoder_a_gpio = 8;
static const uint8_t encoder_b_gpio = 9;
static const uint8_t encoder_sw_gpio = 10;
static const uint8_t touch_gpio = 11;
static const uint8_t rgb_gpio = 12;
static const uint8_t rgb_count = 24;

static const uint8_t keymap[4][4] = {
    {0, HID_KEY_F13, HID_KEY_F14, 0},
    {HID_KEY_F15, HID_KEY_F16, HID_KEY_F17, HID_KEY_F18},
    {HID_KEY_F19, HID_KEY_F20, HID_KEY_F21, HID_KEY_F22},
    {0, HID_KEY_F23, 0, HID_KEY_F24},
};

static uint8_t stable[4][4];
static uint8_t integrator[4][4];
static uint8_t encoder_last;
static int8_t encoder_delta;
static PIO rgb_pio;
static uint rgb_sm;

static void matrix_init(void) {
    for (int row = 0; row < 4; row++) {
        gpio_init(row_gpio[row]);
        gpio_set_dir(row_gpio[row], GPIO_IN);
        gpio_disable_pulls(row_gpio[row]);
    }
    for (int col = 0; col < 4; col++) {
        gpio_init(col_gpio[col]);
        gpio_set_dir(col_gpio[col], GPIO_IN);
        gpio_pull_up(col_gpio[col]);
    }
}

static void scan_matrix(void) {
    for (int row = 0; row < 4; row++) {
        gpio_set_dir(row_gpio[row], GPIO_OUT);
        gpio_put(row_gpio[row], 0);
        sleep_us(8);
        for (int col = 0; col < 4; col++) {
            bool pressed = !gpio_get(col_gpio[col]);
            uint8_t *acc = &integrator[row][col];
            if (pressed && *acc < 5) (*acc)++;
            if (!pressed && *acc > 0) (*acc)--;
            if (*acc == 5) stable[row][col] = 1;
            if (*acc == 0) stable[row][col] = 0;
        }
        gpio_set_dir(row_gpio[row], GPIO_IN);
        gpio_disable_pulls(row_gpio[row]);
    }
}

static void encoder_update(void) {
    uint8_t now = (gpio_get(encoder_a_gpio) << 1) | gpio_get(encoder_b_gpio);
    static const int8_t table[16] = {
        0, -1, 1, 0, 1, 0, 0, -1, -1, 0, 0, 1, 0, 1, -1, 0
    };
    encoder_delta += table[(encoder_last << 2) | now];
    encoder_last = now;
}

static void add_key(uint8_t key, uint8_t keys[6], uint8_t *count) {
    if (key && *count < 6) keys[(*count)++] = key;
}

static uint32_t grb(uint8_t red, uint8_t green, uint8_t blue) {
    return ((uint32_t)green << 16) | ((uint32_t)red << 8) | blue;
}

static void rgb_put(uint32_t pixel_grb) {
    pio_sm_put_blocking(rgb_pio, rgb_sm, pixel_grb << 8u);
}

static bool key_led_pressed(uint8_t index) {
    static const uint8_t positions[12][2] = {
        {0, 1}, {0, 2}, {1, 0}, {1, 1}, {1, 2}, {1, 3},
        {2, 0}, {2, 1}, {2, 2}, {2, 3}, {3, 1}, {3, 3},
    };
    return stable[positions[index][0]][positions[index][1]];
}

static void send_rgb_frame(void) {
    // Maximum channel code is 4/255. Even an all-white fault pattern stays far
    // below the uncontrolled full-brightness current of 24 SK6812 pixels.
    for (uint8_t index = 0; index < rgb_count; index++) {
        uint32_t color;
        if (index < 12) {
            if (key_led_pressed(index)) {
                color = grb(4, 1, 0);              // pressed: warm amber
            } else if (index < 6) {
                color = grb(1, 4, 0);              // agent keys: acid green
            } else {
                color = grb(2, 2, 2);              // command keys: dim white
            }
        } else if (index < 21) {
            color = grb(1, 3, 0);                  // perimeter underglow
        } else {
            color = grb(0, 1, 4);                  // status pixels
        }
        rgb_put(color);
    }
}

static void send_report(void) {
    if (!tud_hid_ready()) return;
    uint8_t keys[6] = {0};
    uint8_t count = 0;

    for (int row = 0; row < 4; row++) {
        for (int col = 0; col < 4; col++) {
            if (stable[row][col]) add_key(keymap[row][col], keys, &count);
        }
    }
    if (!gpio_get(encoder_sw_gpio)) add_key(HID_KEY_KEYPAD_ENTER, keys, &count);
    if (gpio_get(touch_gpio)) add_key(HID_KEY_F12, keys, &count);

    adc_select_input(0);
    uint16_t joy_x = adc_read();
    adc_select_input(1);
    uint16_t joy_y = adc_read();
    if (joy_x < 900) add_key(HID_KEY_ARROW_LEFT, keys, &count);
    if (joy_x > 3200) add_key(HID_KEY_ARROW_RIGHT, keys, &count);
    if (joy_y < 900) add_key(HID_KEY_ARROW_DOWN, keys, &count);
    if (joy_y > 3200) add_key(HID_KEY_ARROW_UP, keys, &count);

    if (encoder_delta >= 4) {
        add_key(HID_KEY_PAGE_UP, keys, &count);
        encoder_delta = 0;
    } else if (encoder_delta <= -4) {
        add_key(HID_KEY_PAGE_DOWN, keys, &count);
        encoder_delta = 0;
    }
    tud_hid_keyboard_report(0, 0, keys);
}

int main(void) {
    board_init();
    tusb_init();
    matrix_init();

    for (uint8_t gpio = encoder_a_gpio; gpio <= encoder_sw_gpio; gpio++) {
        gpio_init(gpio);
        gpio_set_dir(gpio, GPIO_IN);
        gpio_pull_up(gpio);
    }
    gpio_init(touch_gpio);
    gpio_set_dir(touch_gpio, GPIO_IN);
    gpio_pull_down(touch_gpio);
    encoder_last = (gpio_get(encoder_a_gpio) << 1) | gpio_get(encoder_b_gpio);

    rgb_pio = pio0;
    rgb_sm = pio_claim_unused_sm(rgb_pio, true);
    uint rgb_offset = pio_add_program(rgb_pio, &ws2812_program);
    ws2812_program_init(rgb_pio, rgb_sm, rgb_offset, rgb_gpio, 800000, false);
    send_rgb_frame();

    adc_init();
    adc_gpio_init(26);
    adc_gpio_init(27);

    absolute_time_t next_scan = get_absolute_time();
    absolute_time_t next_rgb = get_absolute_time();
    while (true) {
        tud_task();
        if (absolute_time_diff_us(next_scan, get_absolute_time()) >= 0) {
            next_scan = delayed_by_ms(next_scan, 1);
            scan_matrix();
            encoder_update();
            send_report();
        }
        if (absolute_time_diff_us(next_rgb, get_absolute_time()) >= 0) {
            next_rgb = delayed_by_ms(next_rgb, 20);
            send_rgb_frame();
        }
    }
}

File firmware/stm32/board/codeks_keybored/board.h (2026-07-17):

#ifndef BOARD_H_
#define BOARD_H_

#ifdef __cplusplus
extern "C" {
#endif
// Unused spare pins satisfy TinyUSB's generic board API without touching any
// matrix, encoder, touch, joystick, RGB, or USB signal.
#define LED_PORT              GPIOB
#define LED_PIN               GPIO_PIN_14
#define LED_STATE_ON          1
#define BUTTON_PORT           GPIOB
#define BUTTON_PIN            GPIO_PIN_15
#define BUTTON_STATE_ACTIVE   0

static inline void board_stm32f0_clock_init(void)
{
  RCC_ClkInitTypeDef clk = {0};
  RCC_OscInitTypeDef osc = {0};

  osc.OscillatorType = RCC_OSCILLATORTYPE_HSI48;
  osc.HSI48State = RCC_HSI48_ON;
  osc.PLL.PLLState = RCC_PLL_ON;
  osc.PLL.PLLSource = RCC_PLLSOURCE_HSI48;
  osc.PLL.PREDIV = RCC_PREDIV_DIV2;
  osc.PLL.PLLMUL = RCC_PLL_MUL2;
  HAL_RCC_OscConfig(&osc);

  clk.ClockType = RCC_CLOCKTYPE_SYSCLK | RCC_CLOCKTYPE_HCLK | RCC_CLOCKTYPE_PCLK1;
  clk.SYSCLKSource = RCC_SYSCLKSOURCE_PLLCLK;
  clk.AHBCLKDivider = RCC_SYSCLK_DIV1;
  clk.APB1CLKDivider = RCC_HCLK_DIV1;
  HAL_RCC_ClockConfig(&clk, FLASH_LATENCY_1);

  // USB start-of-frame continually trims HSI48 on crystal-less STM32F072.
  __HAL_RCC_CRS_CLK_ENABLE();
  RCC_CRSInitTypeDef crs = {0};
  crs.Prescaler = RCC_CRS_SYNC_DIV1;
  crs.Source = RCC_CRS_SYNC_SOURCE_USB;
  crs.Polarity = RCC_CRS_SYNC_POLARITY_RISING;
  crs.ReloadValue = __HAL_RCC_CRS_RELOADVALUE_CALCULATE(48000000, 1000);
  crs.ErrorLimitValue = RCC_CRS_ERRORLIMIT_DEFAULT;
  crs.HSI48CalibrationValue = RCC_CRS_HSI48CALIBRATION_DEFAULT;
  HAL_RCCEx_CRSConfig(&crs);
}

static inline void board_vbus_sense_init(void) {}

#ifdef __cplusplus
}
#endif

#endif

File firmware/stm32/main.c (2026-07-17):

#include <stdbool.h>
#include <stdint.h>
#include <string.h>

#include "bsp/board_api.h"
#include "stm32f0xx_hal.h"
#include "stm32f0xx_hal_adc.h"
#include "stm32f0xx_hal_adc_ex.h"
#include "tusb.h"

typedef struct { GPIO_TypeDef *port; uint16_t pin; } gpio_t;

static gpio_t const rows[4] = {
  {GPIOA, GPIO_PIN_2}, {GPIOA, GPIO_PIN_3},
  {GPIOA, GPIO_PIN_4}, {GPIOA, GPIO_PIN_5},
};
static gpio_t const cols[4] = {
  {GPIOA, GPIO_PIN_6}, {GPIOA, GPIO_PIN_7},
  {GPIOB, GPIO_PIN_0}, {GPIOB, GPIO_PIN_1},
};
static gpio_t const enc_a = {GPIOB, GPIO_PIN_2};
static gpio_t const enc_b = {GPIOB, GPIO_PIN_10};
static gpio_t const enc_sw = {GPIOB, GPIO_PIN_11};
static gpio_t const touch = {GPIOB, GPIO_PIN_12};
#define RGB_PORT GPIOB
#define RGB_PIN GPIO_PIN_13
#define RGB_COUNT 24

static uint8_t const keymap[4][4] = {
  {0, HID_KEY_F13, HID_KEY_F14, 0},
  {HID_KEY_F15, HID_KEY_F16, HID_KEY_F17, HID_KEY_F18},
  {HID_KEY_F19, HID_KEY_F20, HID_KEY_F21, HID_KEY_F22},
  {0, HID_KEY_F23, 0, HID_KEY_F24},
};
static uint8_t stable[4][4];
static uint8_t integrator[4][4];
static uint8_t encoder_last;
static int8_t encoder_delta;
static ADC_HandleTypeDef hadc;

static void configure_pin(gpio_t gpio, uint32_t mode, uint32_t pull) {
  GPIO_InitTypeDef init = {0};
  init.Pin = gpio.pin;
  init.Mode = mode;
  init.Pull = pull;
  init.Speed = GPIO_SPEED_FREQ_HIGH;
  HAL_GPIO_Init(gpio.port, &init);
}

static void keyboard_io_init(void) {
  for (unsigned i = 0; i < 4; i++) configure_pin(rows[i], GPIO_MODE_INPUT, GPIO_NOPULL);
  for (unsigned i = 0; i < 4; i++) configure_pin(cols[i], GPIO_MODE_INPUT, GPIO_PULLUP);
  configure_pin(enc_a, GPIO_MODE_INPUT, GPIO_PULLUP);
  configure_pin(enc_b, GPIO_MODE_INPUT, GPIO_PULLUP);
  configure_pin(enc_sw, GPIO_MODE_INPUT, GPIO_PULLUP);
  configure_pin(touch, GPIO_MODE_INPUT, GPIO_PULLDOWN);
  configure_pin((gpio_t){RGB_PORT, RGB_PIN}, GPIO_MODE_OUTPUT_PP, GPIO_NOPULL);
  HAL_GPIO_WritePin(RGB_PORT, RGB_PIN, GPIO_PIN_RESET);
  encoder_last = (HAL_GPIO_ReadPin(enc_a.port, enc_a.pin) << 1) |
                 HAL_GPIO_ReadPin(enc_b.port, enc_b.pin);
}

static void adc_init_local(void) {
  GPIO_InitTypeDef analog = {0};
  analog.Pin = GPIO_PIN_0 | GPIO_PIN_1;
  analog.Mode = GPIO_MODE_ANALOG;
  analog.Pull = GPIO_NOPULL;
  HAL_GPIO_Init(GPIOA, &analog);
  __HAL_RCC_ADC1_CLK_ENABLE();
  hadc.Instance = ADC1;
  hadc.Init.ClockPrescaler = ADC_CLOCK_ASYNC_DIV1;
  hadc.Init.Resolution = ADC_RESOLUTION_12B;
  hadc.Init.DataAlign = ADC_DATAALIGN_RIGHT;
  hadc.Init.ScanConvMode = ADC_SCAN_DIRECTION_FORWARD;
  hadc.Init.EOCSelection = ADC_EOC_SINGLE_CONV;
  hadc.Init.LowPowerAutoWait = DISABLE;
  hadc.Init.LowPowerAutoPowerOff = DISABLE;
  hadc.Init.ContinuousConvMode = DISABLE;
  hadc.Init.DiscontinuousConvMode = DISABLE;
  hadc.Init.ExternalTrigConv = ADC_SOFTWARE_START;
  hadc.Init.ExternalTrigConvEdge = ADC_EXTERNALTRIGCONVEDGE_NONE;
  hadc.Init.DMAContinuousRequests = DISABLE;
  hadc.Init.Overrun = ADC_OVR_DATA_PRESERVED;
  HAL_ADC_Init(&hadc);
  HAL_ADCEx_Calibration_Start(&hadc);
}

static uint16_t adc_read_channel(uint32_t channel) {
  ADC_ChannelConfTypeDef config = {0};
  config.Channel = channel;
  config.Rank = ADC_RANK_CHANNEL_NUMBER;
  config.SamplingTime = ADC_SAMPLETIME_41CYCLES_5;
  HAL_ADC_ConfigChannel(&hadc, &config);
  HAL_ADC_Start(&hadc);
  HAL_ADC_PollForConversion(&hadc, 2);
  uint16_t result = (uint16_t)HAL_ADC_GetValue(&hadc);
  HAL_ADC_Stop(&hadc);
  return result;
}

static void scan_matrix(void) {
  for (unsigned row = 0; row < 4; row++) {
    configure_pin(rows[row], GPIO_MODE_OUTPUT_PP, GPIO_NOPULL);
    HAL_GPIO_WritePin(rows[row].port, rows[row].pin, GPIO_PIN_RESET);
    for (volatile unsigned delay = 0; delay < 40; delay++) __NOP();
    for (unsigned col = 0; col < 4; col++) {
      bool pressed = HAL_GPIO_ReadPin(cols[col].port, cols[col].pin) == GPIO_PIN_RESET;
      uint8_t *acc = &integrator[row][col];
      if (pressed && *acc < 5) (*acc)++;
      if (!pressed && *acc > 0) (*acc)--;
      if (*acc == 5) stable[row][col] = 1;
      if (*acc == 0) stable[row][col] = 0;
    }
    configure_pin(rows[row], GPIO_MODE_INPUT, GPIO_NOPULL);
  }
}

static void encoder_update(void) {
  uint8_t now = (HAL_GPIO_ReadPin(enc_a.port, enc_a.pin) << 1) |
                HAL_GPIO_ReadPin(enc_b.port, enc_b.pin);
  static int8_t const table[16] = {
    0, -1, 1, 0, 1, 0, 0, -1, -1, 0, 0, 1, 0, 1, -1, 0
  };
  encoder_delta += table[(encoder_last << 2) | now];
  encoder_last = now;
}

static inline void rgb_delay(unsigned count) {
  while (count--) __NOP();
}

static void rgb_bit(bool one) {
  RGB_PORT->BSRR = RGB_PIN;
  rgb_delay(one ? 17 : 6);
  RGB_PORT->BRR = RGB_PIN;
  rgb_delay(one ? 7 : 18);
}

static void rgb_word(uint32_t grb) {
  for (int bit = 23; bit >= 0; bit--) rgb_bit((grb >> bit) & 1u);
}

static uint32_t grb(uint8_t red, uint8_t green, uint8_t blue) {
  return ((uint32_t)green << 16) | ((uint32_t)red << 8) | blue;
}

static bool key_led_pressed(uint8_t index) {
  static uint8_t const positions[12][2] = {
    {0,1}, {0,2}, {1,0}, {1,1}, {1,2}, {1,3},
    {2,0}, {2,1}, {2,2}, {2,3}, {3,1}, {3,3},
  };
  return stable[positions[index][0]][positions[index][1]];
}

static void send_rgb_frame(void) {
  __disable_irq();
  for (uint8_t i = 0; i < RGB_COUNT; i++) {
    uint32_t color;
    if (i < 12) color = key_led_pressed(i) ? grb(4,1,0) : (i < 6 ? grb(1,4,0) : grb(2,2,2));
    else if (i < 21) color = grb(1,3,0);
    else color = grb(0,1,4);
    rgb_word(color);
  }
  __enable_irq();
  HAL_Delay(1);
}

static void add_key(uint8_t key, uint8_t keys[6], uint8_t *count) {
  if (key && *count < 6) keys[(*count)++] = key;
}

static void send_report(void) {
  if (!tud_hid_ready()) return;
  uint8_t keys[6] = {0};
  uint8_t count = 0;
  for (unsigned row = 0; row < 4; row++)
    for (unsigned col = 0; col < 4; col++)
      if (stable[row][col]) add_key(keymap[row][col], keys, &count);
  if (HAL_GPIO_ReadPin(enc_sw.port, enc_sw.pin) == GPIO_PIN_RESET)
    add_key(HID_KEY_KEYPAD_ENTER, keys, &count);
  if (HAL_GPIO_ReadPin(touch.port, touch.pin) == GPIO_PIN_SET)
    add_key(HID_KEY_F12, keys, &count);

  uint16_t x = adc_read_channel(ADC_CHANNEL_0);
  uint16_t y = adc_read_channel(ADC_CHANNEL_1);
  if (x < 900) add_key(HID_KEY_ARROW_LEFT, keys, &count);
  if (x > 3200) add_key(HID_KEY_ARROW_RIGHT, keys, &count);
  if (y < 900) add_key(HID_KEY_ARROW_DOWN, keys, &count);
  if (y > 3200) add_key(HID_KEY_ARROW_UP, keys, &count);
  if (encoder_delta >= 4) { add_key(HID_KEY_PAGE_UP, keys, &count); encoder_delta = 0; }
  if (encoder_delta <= -4) { add_key(HID_KEY_PAGE_DOWN, keys, &count); encoder_delta = 0; }
  tud_hid_keyboard_report(0, 0, keys);
}
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

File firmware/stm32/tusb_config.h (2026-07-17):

#pragma once

#ifndef BOARD_TUD_RHPORT
#define BOARD_TUD_RHPORT 0
#endif
#ifndef BOARD_TUD_MAX_SPEED
#define BOARD_TUD_MAX_SPEED OPT_MODE_FULL_SPEED
#endif
#ifndef CFG_TUSB_MCU
#error CFG_TUSB_MCU must be defined by the TinyUSB STM32F0 family build
#endif
#ifndef CFG_TUSB_OS
#define CFG_TUSB_OS OPT_OS_NONE
#endif

#define CFG_TUD_ENABLED 1
#define CFG_TUD_MAX_SPEED BOARD_TUD_MAX_SPEED
#define CFG_TUSB_DEBUG 0
#define CFG_TUSB_MEM_ALIGN __attribute__((aligned(4)))
#define CFG_TUD_ENDPOINT0_SIZE 64
#define CFG_TUD_HID 1
#define CFG_TUD_CDC 0
#define CFG_TUD_MSC 0
#define CFG_TUD_MIDI 0
#define CFG_TUD_VENDOR 0
#define CFG_TUD_HID_EP_BUFSIZE 16

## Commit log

2026-07-17 Publish CODEX KEYBORED Rev A2
    [CM2-001_upper_housing.step, CM2-001_upper_housing_top_profile.dxf, CM2-002_bottom_weight.step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]
2026-07-18 Add manufacturing-ready Rev B ring mechanics
    [CM2-001_upper_housing.step, CM2-001_upper_housing_top_profile.dxf, CM2-002_bottom_weight.step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]
2026-07-18 Add JLCCNC laser marking response package
    [CM2-002_LASER_ARTWORK_ONLY_RevB.dxf, CM2-002_LASER_PLACEMENT_REFERENCE_RevB.dxf]
